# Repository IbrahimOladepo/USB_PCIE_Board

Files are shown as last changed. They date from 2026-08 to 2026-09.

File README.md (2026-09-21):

# USB PCIe Expansion Card

A PCI Express x1 to USB 3.0 expansion card, designed in KiCad. Plugs into a PCIe x1
slot and breaks it out to four USB 3.0 Type-A ports.

## Contents

- [Overview](#overview)
- [Board](#board)
- [Design approach](#design-approach)
- [First assembled board (v0.1)](#first-assembled-board-v01)
  - [The R25 bring-up bug and the through-hole fix](#the-r25-bring-up-bug-and-the-through-hole-fix)
  - [Running in a PC](#running-in-a-pc)
  - [Known issues](#known-issues-to-fix-in-the-next-revision)
- [Component sorting tray](#component-sorting-tray)
- [OS / driver setup](#os--driver-setup)
  - [Windows](#windows)
  - [Linux](#linux)
- [Repository layout](#repository-layout)
- [Status](#status)

## Overview

The design is built around **U1**, a Renesas `µPD720201` xHCI USB 3.0 host
controller, which bridges the PCIe link to four independent USB 3.0 ports.

| Function | Reference(s) | Part |
|---|---|---|
| PCIe x1 edge connector | J1 | `Bus_PCI_Express_x1` |
| USB host controller | U1 | Renesas `UPD720201K8-701-BAC-A` |
| Controller firmware/config flash | U2 | `MX25L4006EM1I-12G` (SPI NOR) |
| Controller clock | X1 | 24MHz crystal |
| USB 3.0 Type-A ports | J2–J5 | Molex `48406-0001` |
| Per-port VBUS power switches | U8–U11 | `AP2191SG-13` |
| Per-port ESD protection | U12–U15 | `SP3011-06UTG` |
| Power regulation | U3, U4, U5, U7 | Buck regulators + 3.3V LDO |

Power for the board and its 5V VBUS rails is derived from the PCIe slot's 12V/3.3V
supply through an on-board regulation chain.

## Board

- 4-layer, ~98.6 x 111.9mm
- ~175 components, ~126 nets

| Top | Bottom |
|---|---|
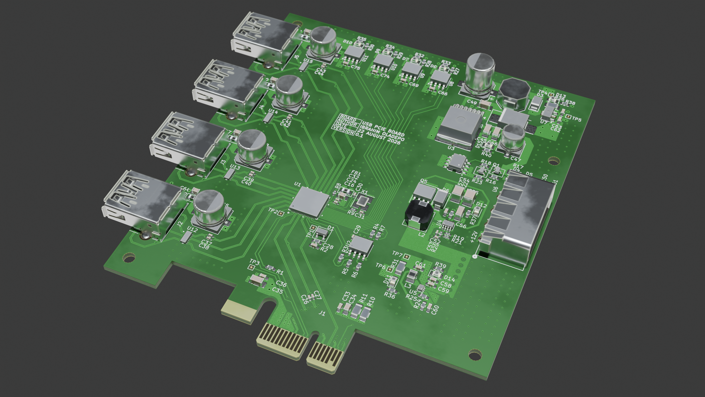
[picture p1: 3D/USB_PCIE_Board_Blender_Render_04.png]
Top isometric render
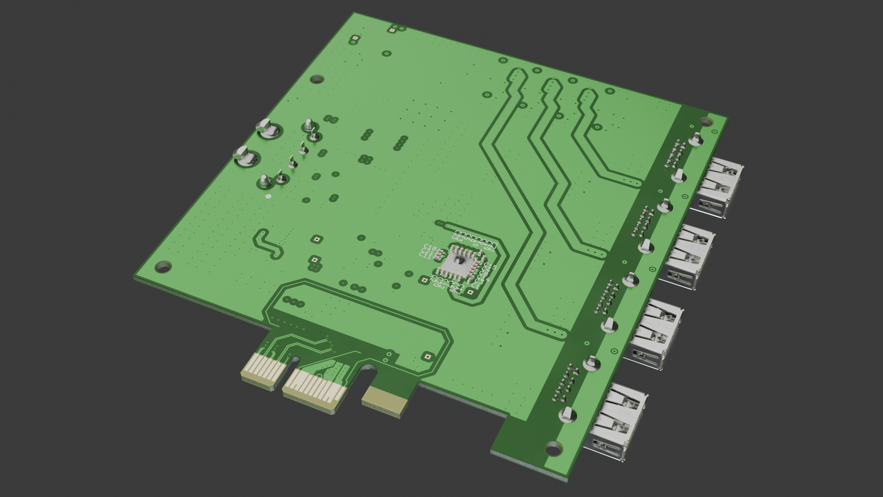
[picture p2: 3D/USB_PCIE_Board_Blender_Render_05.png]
Bottom isometric render
|  |  |

## Design approach

- **All tracks were routed by hand.** No autorouter and no AI-generated routing was
  used.
- **The layer stackup was worked out by me**, following recommendations from
  experts such as Rick Hartley.
- **Claude (Anthropic's AI assistant) was used for repository version control and as
  a second pair of eyes for checking nets for errors.** It did not route or place
  anything. Layout and design decisions are my own.

## First assembled board (v0.1)

| Top | Bottom |
|---|---|
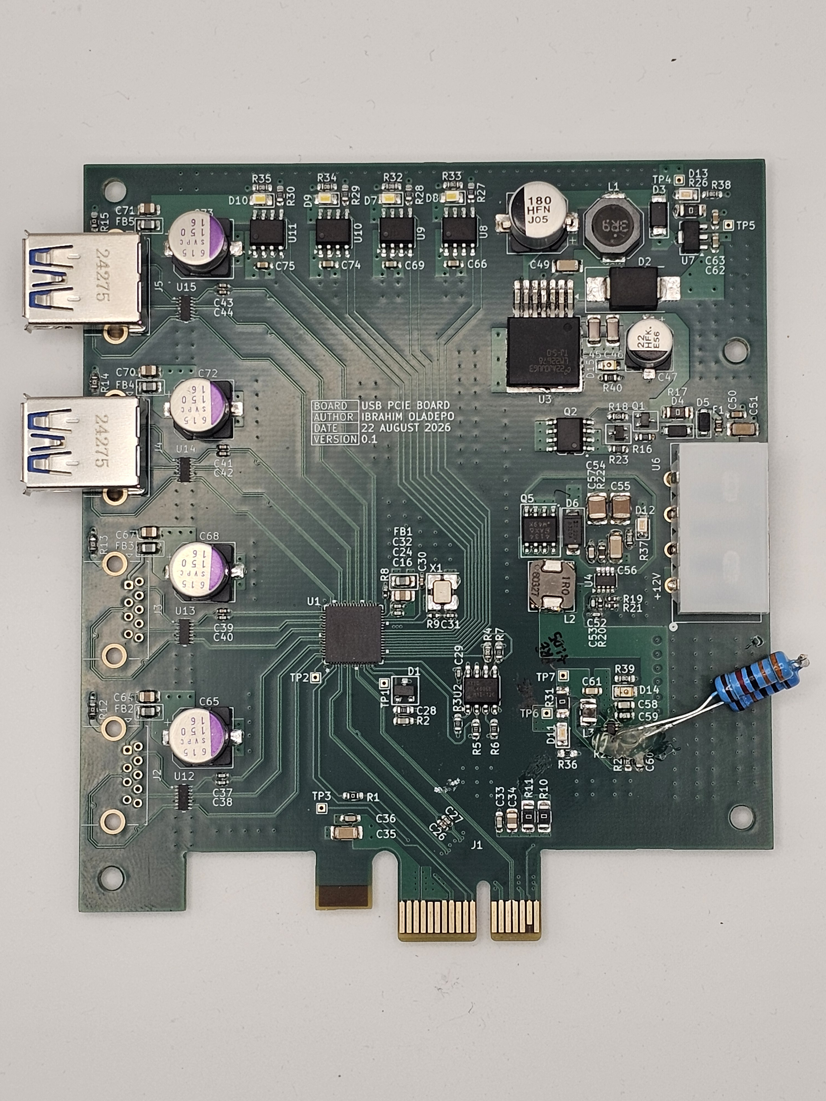
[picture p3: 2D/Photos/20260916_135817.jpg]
Top view, assembled v0.1
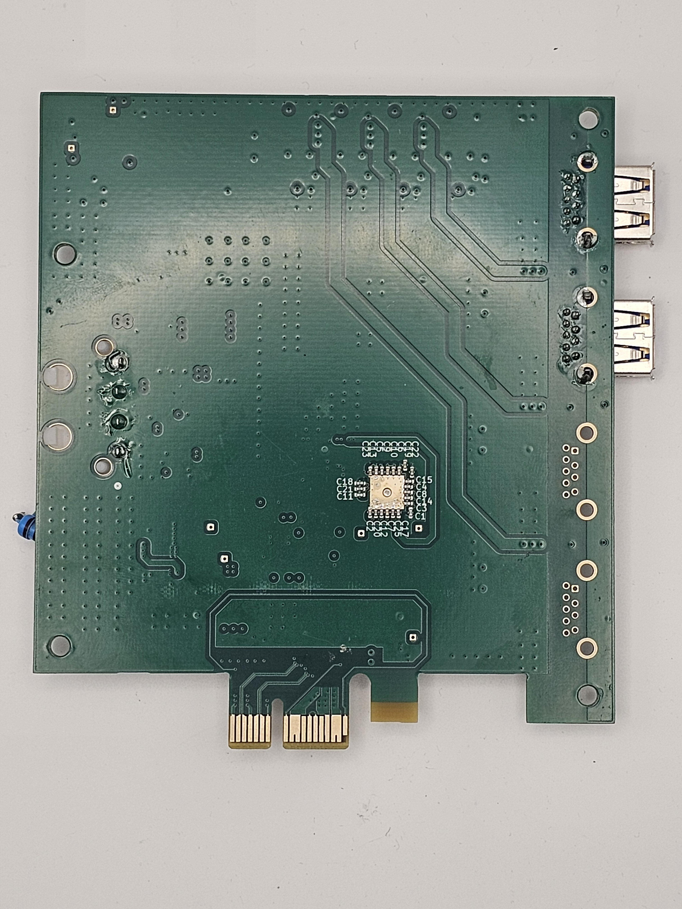
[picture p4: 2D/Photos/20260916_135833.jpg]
Bottom view, assembled v0.1
|  |  |

### The R25 bring-up bug and the through-hole fix

The first populated board brought up all rails cleanly except the 1.05V core rail
(U5), which came up equal to its input voltage instead of regulating. Bring-up debug
(solder-bridge check, continuity check, a U5 swap that didn't help) eventually traced
it to the feedback divider: **R25 had been sourced as a 133Ω part instead of the
133kΩ the design called for**, a unit typo (Ω vs kΩ) that slipped through to the BOM
and the order. With R24 (100kΩ, correct) on top and a 133Ω part on the bottom, the
feedback node was pulled to nearly 0V, which made the regulator's control loop drive
close to 100% duty cycle: output tracking input, exactly as observed.

The through-hole resistors visible in the top-view photo (bottom right, near L3/D14)
are the quick fix: a **100kΩ + 33kΩ series pair (133kΩ total)** from parts already on
hand, soldered in place of the bad R25 so the divider is back at its design value
(1.05V output) without waiting on a new part order.

### Running in a PC

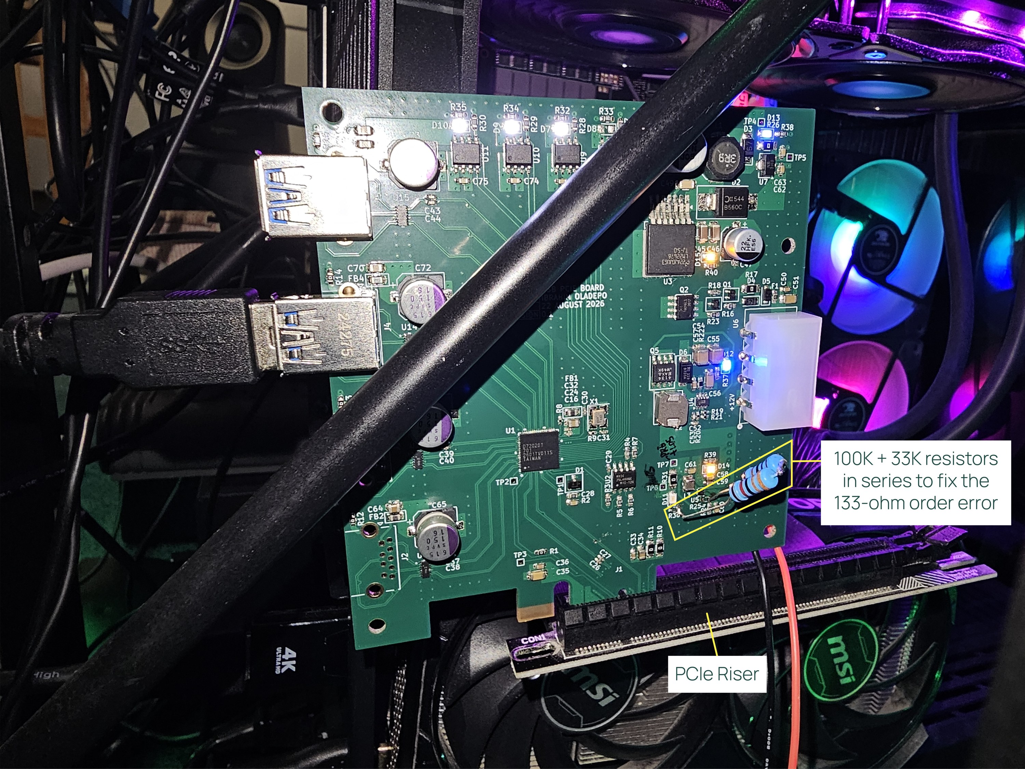
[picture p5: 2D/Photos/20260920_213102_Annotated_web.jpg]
v0.1 board running in a PC through a PCIe riser, with the R25 fix and riser annotated


The board is plugged into the PC's PCIe slot through a **PCIe riser**, for two
reasons: it makes the board easy to probe with a multimeter while powered, and the
case has no room for the board's USB connector placement when seated directly in the
slot. The annotated photo marks the R25 fix and the riser. The original,
un-annotated photo is
[`2D/Photos/20260920_213102.jpg`](2D/Photos/20260920_213102.jpg).

A 1TB SSD connected to one of the board's USB ports, tested with CrystalDiskMark:

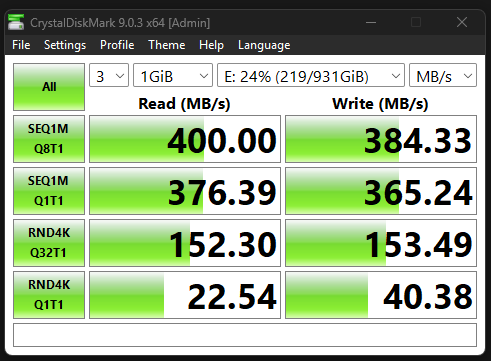
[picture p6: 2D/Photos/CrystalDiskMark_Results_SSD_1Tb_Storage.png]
CrystalDiskMark results for a 1TB SSD on the board


| Test | Read (MB/s) | Write (MB/s) |
|---|---|---|
| SEQ1M Q8T1 | 400.00 | 384.33 |
| SEQ1M Q1T1 | 376.39 | 365.24 |
| RND4K Q32T1 | 152.30 | 153.49 |
| RND4K Q1T1 | 22.54 | 40.38 |

### Known issues (to fix in the next revision)

- **1.05V indicator LED (D11) cannot light.** D11 is a blue `SMLMN2BCTT86C` with a
  forward voltage of about 2.9V, but it is wired across the 1.05V rail, so it can
  never turn on. Note that swapping to a lower-Vf colour will not fix this on its own:
  a red/yellow/green LED still needs roughly 1.8V or more. Options for v0.2: drive
  the LED from +3V3 through a resistor and switch it with a small transistor sensed
  from +1V05, or drop the LED and rely on the TP6/TP7 test points.
- **R25 value.** Re-check the schematic/BOM value and the ordered part for R25 so they
  match the intended 133kΩ before the next order.
- See [`Doc/PCB_Design_Review_Checklist.md`](Doc/PCB_Design_Review_Checklist.md) for the
  rest of the v0.1 review notes.

## Component sorting tray

A 150 x 150 x 10mm box-and-lid pair for sorting the BOM by hand before assembly, one
compartment per distinct part/value. Generated with the
[box-stl-generator](https://javisperez.github.io/box-stl-generator/) tool; STL files
are in `3D/Assembly/`. Pair it with `Doc/Component_Tray_Layout.pdf` for a printable,
to-scale cut-out label plus a lookup table mapping each compartment to its BOM entry.

| Box | Lid |
|---|---|
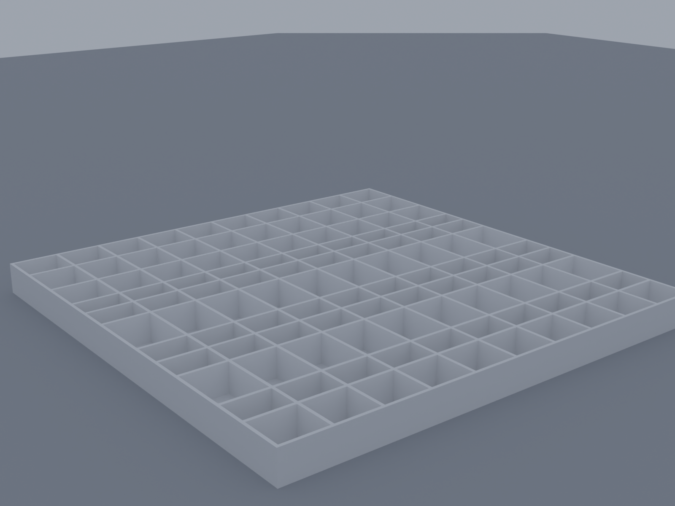
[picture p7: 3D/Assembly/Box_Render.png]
Box render
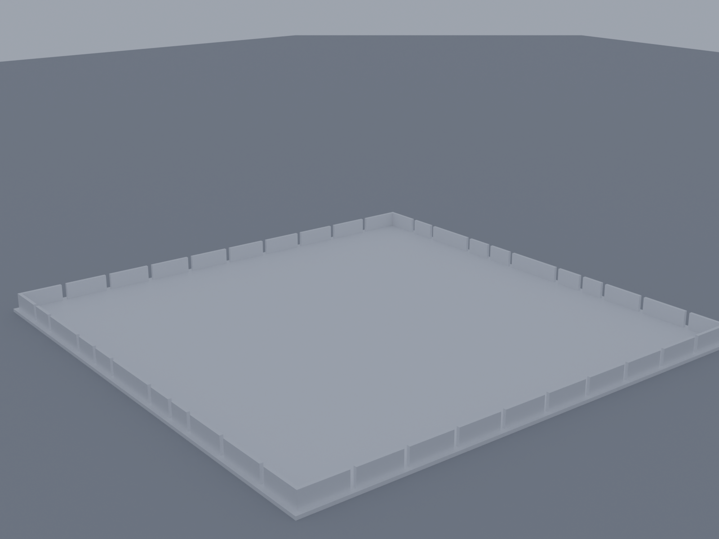
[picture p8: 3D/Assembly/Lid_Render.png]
Lid render
|  |  |

## OS / driver setup

### Windows

Windows Update alone was enough to bring the controller up correctly. In addition, the
[Renesas USB 3.0 Host Controller Driver](https://www.dell.com/support/home/en-fm/drivers/driversdetails?driverid=1ptn7)
(distributed via Dell's driver site) was installed. No manual firmware extraction step
was needed on Windows, unlike Linux.

### Linux

This board uses the Renesas `UPD720201K8-701-BAC-A` PCIe to USB 3.0 host controller. On
Linux, the `xhci-pci-renesas` driver requires a firmware blob to bring the controller
online. That firmware is not distributed through the standard `linux-firmware` package
due to Renesas licensing restrictions, so it has to be installed manually. The steps
below worked on Ubuntu (kernel 7.0.x).

**1. Confirm the board is enumerating on PCIe**

Before touching firmware, confirm the OS sees the chip at all:

```bash
lspci -d 1912:
```

If nothing shows up, this is a hardware bring-up issue (power sequencing, REFCLK/PERST#
timing, card edge connector, or PCIe slot lane availability), not a firmware issue.
Check `sudo dmesg | grep -iE "pci|xhci"` around boot time for enumeration messages
before proceeding.

Once the chip enumerates correctly, you'll see something like:

```
xhci-pci-renesas 0000:01:00.0: probe with driver xhci-pci-renesas failed with error -2
```

The `-2` (ENOENT) confirms the driver bound successfully but could not find the
firmware file.

**2. Get the firmware**

The `linux-firmware` package does not ship `renesas_usb_fw.mem` for this chip family.
Use the community-maintained mirror instead, which repackages the firmware extracted
from Renesas's official Windows update tool along with checksums:

```bash
cd /tmp
wget https://github.com/chunkeey/renesas-fw/raw/master/USB3-201-202-FW-20120615.zip
wget https://github.com/chunkeey/renesas-fw/raw/master/SHA256SUMS
sha256sum -c SHA256SUMS 2>/dev/null | grep -i ok
unzip USB3-201-202-FW-20120615.zip -d renesas-fw-extracted
```

This covers both the uPD720201 and uPD720202 with a single combined firmware image:
`K2013080.mem`.

**3. Install the firmware**

```bash
sudo cp /tmp/renesas-fw-extracted/USB3-201-202-FW-20120615/K2013080.mem /lib/firmware/renesas_usb_fw.mem
file /lib/firmware/renesas_usb_fw.mem   # should report "data", not ASCII/HTML
sudo update-initramfs -u
sudo reboot
```

**4. Verify**

```bash
sudo dmesg | grep -i renesas
lsusb
```

Expected output on success:

```
xhci-pci-renesas 0000:01:00.0: xHCI Host Controller
xhci-pci-renesas 0000:01:00.0: new USB bus registered, assigned bus number 3
xhci-pci-renesas 0000:01:00.0: new USB bus registered, assigned bus number 4
xhci-pci-renesas 0000:01:00.0: Host supports USB 3.0 SuperSpeed
usb 4-1: new SuperSpeed USB device number 2 using xhci-pci-renesas
```

A device plugged into the hub should now show up in `lsusb` as a SuperSpeed device on
the new bus.

**Notes**

- This firmware image is dated 2012. Renesas has released newer versions since; if you
  hit driver errors that this image does not resolve, pull an updated version directly
  from Renesas's site (free account required) rather than a community mirror.
- Because the firmware is not redistributable through `linux-firmware`, this manual
  install step will need to be repeated after a fresh OS install or if `/lib/firmware`
  gets wiped. Consider scripting steps 2 to 3 as a setup script in this repo for future
  bring-up.

## Repository layout

- `USB_PCIE_Board.kicad_pro` / `.kicad_pcb` / `.kicad_sch` — main project, board, and schematic
- `USB_PCIE_BOARD_POWER.kicad_sch` — power supply schematic sheet
- `Doc/` — documentation, including a PCB design review checklist and the component
  tray layout
- `2D/` — board edge outline drawings (`.dxf` / `.ai`), and `2D/Photos/` with photos of
  the assembled v0.1 board and its bring-up
- `3D/` — Blender renders and STEP/pcb3d exports of the board; `3D/Assembly/` has the
  sorting tray's STL files and renders
- `bom/` — interactive HTML BOM (`ibom.html`)
- `production/` — generated fabrication outputs (gerbers, BOM, position files)

## Status

Actively being worked through a design review pass (DRC cleanup, courtyard/footprint
fixes, silkscreen check) — see `Doc/PCB_Design_Review_Checklist.md` for the current
punch list.

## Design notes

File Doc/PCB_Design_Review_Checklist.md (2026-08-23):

# PCB Design & Review Checklist

Source: [Altium — PCB Design and Review Checklist](https://resources.altium.com/p/pcb-design-and-review-checklist)
(Mark Harris, updated 2026-08-10). Full article saved at
`Doc/PCB Design Review Checklist _ Blog _ Altium.PDF`.

> Per the article: treat each item as a **discussion point**, not just a box to tick —
> the goal is confirming the design meets intent, not just clearing a checklist. Not
> every item applies to every board; mark N/A with a short reason rather than deleting
> a line, so the reasoning is preserved for next time.

Check items off as `[x]` as we work through the design. Notes on findings go inline
under each item.

**Review pass 2026-08-22** (via KiCAD MCP tools — DRC, courtyard/boundary check, zone
query, ratsnest, board geometry). Items with a **Findings:** line were checked against
the live board; everything else needs a manual/visual pass (silkscreen artwork,
mechanical fit, simulation) that wasn't possible from this session.

## Before Submitting for Review

- [x] Check for unrouted nets
  - **Findings:** No unconnected-items errors in DRC; board shows 1315 tracks / 575 vias
    across 126 nets. Appears fully routed.
- [ ] Repour all polygons
  - **Findings:** All 92 copper zones report `isFilled: true` in the current save — no
    stale/unfilled zones detected. Still worth doing an explicit "Refill All Zones" +
    re-save right before final DRC, since this only reflects the last fill on disk.
- [ ] Complete silkscreen, including:
  - [ ] Company logo(s) — not checkable via this tooling, visual check needed
  - [ ] Product logo(s) — visual check needed
  - [ ] Copyright notice — visual check needed
  - [ ] Warning/hazard label(s) and icons — visual check needed (likely N/A, board carries no hazardous voltages)
  - [ ] Connectors labeled, pinouts called out where relevant — visual check needed
  - [ ] QA/Test block with barcode, blank areas for serial number, dates, QA/Test checkmarks — not found in any pass this session; likely missing
  - [ ] Board name, print date, and revision number — title block metadata exists (title "USB PCIE Expansion Card Board", rev "0.1") but that's project metadata, not confirmed to be rendered as silkscreen text — visual check needed
  - [x] If there are designators on the silkscreen, then check:
    - [x] Each designator close to and clearly identifies its component
    - [x] All designators only in one or two orientations
    - [x] Text size/font legible after fabrication
    - **Findings:** DRC found 1 `silk_overlap` warning near U1 (86.82, 111.34mm) and 8
      `silk_edge_clearance` warnings **all at the same point** — the board's bottom-left
      corner (51.45, 145.26mm), right by the PCIe-connector notch. Something on
      silkscreen there is being clipped by the board edge — worth a direct look at that
      corner.
  - [x] ICs have pin-1 clearly marked (not under another component) — visual check needed
- [x] PCB updated from schematic — schematic and board are synchronized
  - **Findings:** Mounting holes (H1–H4) were just added to the schematic to match the
    board this session. Re-run "Update PCB from Schematic" once more to confirm there's
    nothing else outstanding.
- [ ] Design rule report passes with no errors
  - **Findings: currently fails — 257 errors, 15 warnings (272 total).** Breakdown:
    - **199 × `via_dangling` (error)** — by far the largest bucket (77% of all errors).
      "Via is not connected or connected on only one layer." Locations are spread
      broadly around the board perimeter and near GND-heavy areas, consistent with GND
      stitching vias that only land on the inner plane on one side. This is the single
      highest-leverage fix — resolving it clears most of the error count.
    - **50 × `hole_clearance` (error)** — all reported as ~0.186–0.197mm actual vs.
      0.200mm required (off by hundredths of a mm), tightly clustered around
      x 85–92mm / y 101–111mm — exactly U1's decoupling-capacitor via fan-out. See the
      Signal Path section below.
    - **8 × `malformed_courtyard` (error)** — same footprint, at 4 evenly-spaced
      y-positions (52.5, 75.8, 99.0, 122.5mm) matching the 4 USB port rows — this is the
      ferrite bead footprint used at FB2–FB5 (one per port). The courtyard on that
      footprint isn't a closed shape — a footprint-library definition issue, not a
      placement issue, so fixing the footprint fixes all 4 instances at once.
    - **5 × `lib_footprint_mismatch` (warning)** — H1, H2, H3, H4
      (`MountingHole_3.2mm_M3`) and J1 (`BUS_PCIexpress_x1`) have all diverged from
      their library originals. Needs a decision: accept the local edits, or
      "Update Footprint from Library" to resync.
    - **1 × `silk_overlap` (warning)** near U1 (86.82, 111.34mm) — see silkscreen note above.
    - **1 × `copper_sliver` (warning)** on F.Cu — no precise location reported by the tool.
  - [ ] A design rule exists to catch nets with only 1 pin — not directly checkable via
        DRC; this is normally an ERC (schematic) check — recommend running ERC.
- [x] Board outline present on a mechanical layer that goes to the fabricator
  - **Findings:** Present — 25 Edge.Cuts segments/arcs forming a closed outline,
    98.64 × 111.9mm extents.
- [ ] Fiducials present for assembly:
  - [ ] Minimum three board-level fiducials included
  - [ ] Two fiducials diagonally opposing each other across all extremely fine-pitch components
  - **Findings: none found.** No footprint with "fiducial" in its name or footprint
    library reference appears anywhere on the board. Given U1 is a QFN68 at 0.4mm pitch,
    fiducials are worth adding before this goes to an assembler.
- [ ] Mounting points have sufficient clearance for the chosen washer and screw head
  - **Findings:** H1–H4 exist as M3 holes (3.2mm drill), but exact copper/silk clearance
    against a specific washer spec wasn't checked. One thing worth confirming visually:
    C71's courtyard overlaps H1's courtyard by ~0.86mm² — make sure the cap doesn't
    physically conflict with a washer at that hole.
- [ ] If an enclosure model is available, it's been tested against the board
  - [ ] All components (including mechanical items) have accurate 3D models
  - Not checkable this session — no enclosure model was referenced. Manual step if this board is going into an enclosure.

## Layers

- [x] Layer stack and substrate heights meet the fabricator's specifications
  - **Findings:** 4 copper layers confirmed via the gerber export (F.Cu, In1.Cu, In2.Cu, B.Cu).
- [x] Copper thickness on all layers matches the fabricator's spec
  - Not checked against a specific fab's stackup table — compare against your chosen
    fab's (e.g. JLCPCB) published stackup before ordering.
- [x] At least one continuous, unbroken ground plane
  - **Findings:** In1.Cu carries a single GND zone spanning ~9310mm² of the ~11000mm²
    board area — reads as the dedicated ground-plane layer.
- [x] Controlled-impedance nets correctly set up in both the layer stack and design rules
  - **Findings:** `get_design_rules` only surfaced one global clearance/track-width rule
    set (0.09mm min clearance, 0.2mm default track width) — no per-netclass differential
    pair rule was visible from this tool. Worth confirming directly in KiCad that the
    USB3 SuperSpeed pairs and PCIe lanes have their own netclass with a differential
    width/gap tuned to 90Ω for your actual stackup.
  - Also flagged: the board's default min clearance/trace width (0.09mm / ~3.5 mil) is
    tighter than many standard-tier fab processes support (commonly 5 mil / 0.127mm
    minimum) — worth double-checking your fab can hit this, unless it was intentionally
    set for an HDI-capable process.
- [x] Any keep-out track matches the board shape
  - [x] Board cutouts/slots have keep-out barriers to prevent nets crossing milled areas
  - Not checked this session.

## Signal Path

- [x] Differential pair tracks are as close together as possible / lengths matched
  - **Findings:** 0 diff-pair-related DRC violations found now, consistent with the
    "Fix skew on differential pair lines" work already in the commit history.
- [ ] Decoupling capacitor vias are not shared — each cap has its own via for VCC and GND
  - **Findings:** U1 has ~30 decoupling caps packed tightly around it — courtyard scan
    shows many overlapping U1's own courtyard boundary by ~2.29mm² each, with vias
    clustered at x 85–92mm / y 101–111mm — the same region producing the 50
    `hole_clearance` DRC errors above. These two findings point at the same spot: worth
    a dedicated look at whether adjacent caps' vias are packed tighter than the 0.2mm
    hole-clearance rule allows.
- [ ] Everything else in this section (via sizing for current capacity, reference-plane
      track width, controlled-impedance profile continuity, crosstalk simulation,
      termination placement) — not checkable from static geometry alone; needs
      simulation or a dedicated manual pass.

## Components

- [x] Courtyard overlaps / clearance
  - **Findings:** `check_courtyard_overlaps` found 83 overlapping courtyard pairs (many
    are tight-packed 0402/0201 decoupling caps around U1 and connector-area parts —
    common in dense fan-out, but worth a skim) and, more notably, **5 boundary
    violations against the board edge**:
    - **J1** (PCIe edge connector) exceeds the board's bottom edge by 0.33mm
    - **J2, J3, J4, J5** (USB-A connectors) each exceed the board's left edge by 7.4mm
  - The USB-connector overhang is very likely intentional — horizontal Type-A shells
    commonly cantilever past the PCB edge into the port opening — but worth a 3D-view
    check to confirm the shells land where an enclosure/bracket expects them. J1's
    0.33mm overhang is worth a closer look specifically: PCIe card-edge fingers need a
    precise setback from the physical board edge per the PCIe CEM spec, so confirm this
    isn't the golden fingers themselves creeping past where they should be.
- [x] Bypass capacitors placed close to IC power pins (under 15mm)
  - **Findings:** U1's decoupling caps sit within ~1–2.3mm of its pins — well under the
    15mm guideline.
- [ ] Everything else (pick-and-place/hand-assembly/rework clearance, crystal-to-clock-pin
      distance, termination-resistor placement, EMI/RFI filter placement, potentiometer
      direction, thermal-mass separation, heat-sinking copper area) — not checkable from
      this data; needs a visual/BOM-level pass.

## Testing

- [ ] Test point inventory and placement
  - **Findings:** Test points exist (at least TP2, TP6 seen in this session's queries),
    but a full inventory, side-consistency check (all on one side), and edge-clearance
    check weren't completed. Worth a manual pass to confirm every rail and every
    diff pair you'd want to probe has one, and they're all reachable from the same side.

## Protection / EMI / EMC

- [x] ESD mitigation components in series with the protected signal
  - **Findings:** U12–U15 (SP3011-06UTG TVS diode arrays) are wired one per USB port,
    matching the "ESD event must pass through the component before reaching a sensitive
    device" requirement. Exact routing order (TVS before host controller pins) wasn't
    independently re-verified pad-by-pad this session.
- [ ] Everything else (creepage/clearance for high-voltage nets — likely N/A, board
      carries no mains voltage; ground loops; track width vs. current for +12V/+5V
      rails; RF shield footprint) — not checked in this pass.

## Panels

*Only applies if this board is being ordered/assembled as part of a multi-board panel.*

- **N/A** — the `production/` export is single-board gerbers, not a panel.

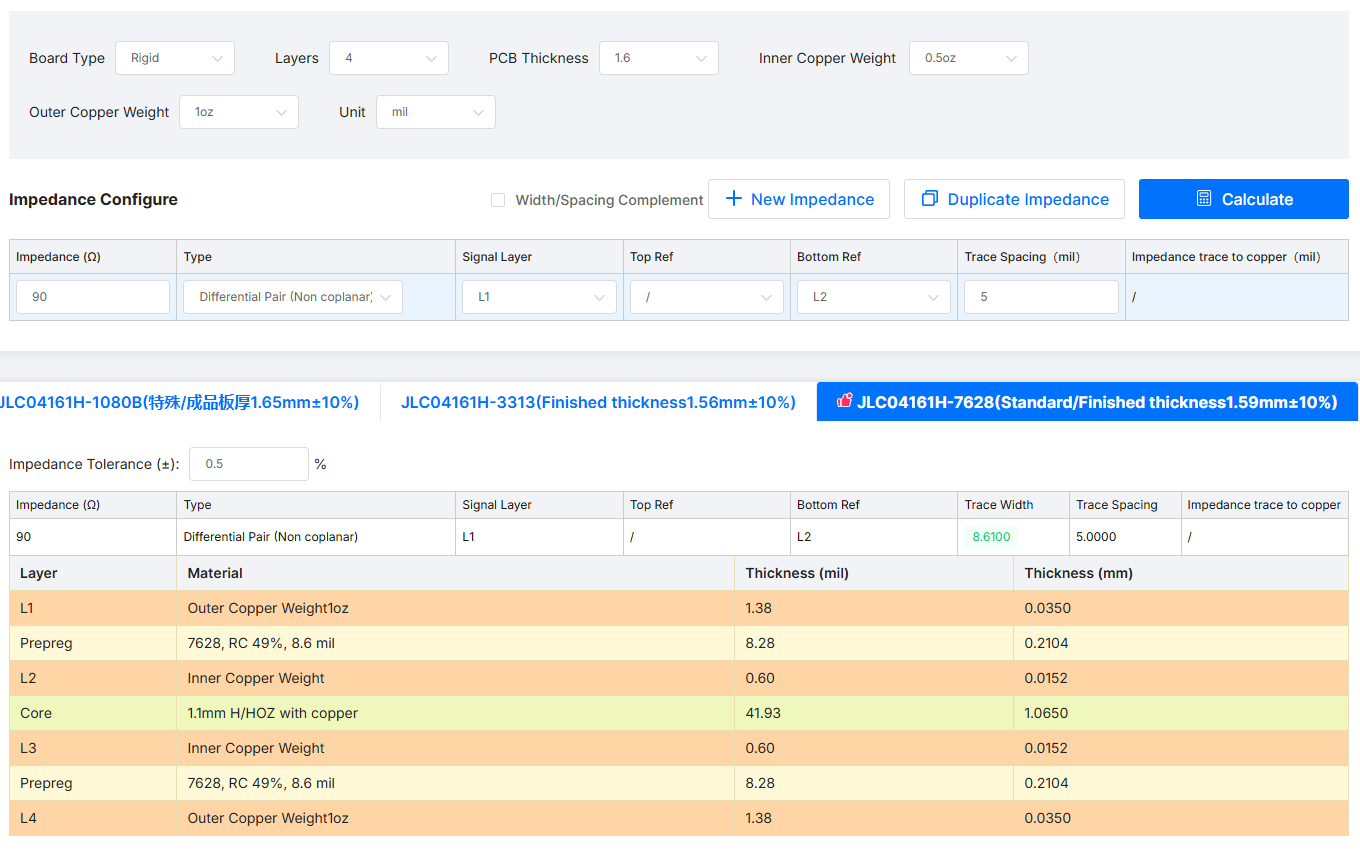
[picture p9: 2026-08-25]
Doc/JLCPCB_Impedance_Calculation.png

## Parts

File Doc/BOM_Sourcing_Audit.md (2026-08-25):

# BOM Sourcing Audit (JLCPCB/LCSC)

Checked 2026-08-23 against a local snapshot of the JLCPCB parts catalog (633,703
in-stock parts, downloaded via the KiCad MCP JLCPCB integration). Source BOM:
`production/USB_PCIE_Board.csv`.

## Headline finding

Every part present in the snapshot has a first price-break tier of **"1+"** — none
carry a JLCPCB SMT-assembly MOQ above 1 unit. The high-MOQ warning seen on LCSC's site
is most likely their separate loose-part/reel retail MOQ, not the JLCPCB assembly MOQ
this database tracks. Worth confirming which flow (assembly vs. loose-part purchase)
produced that warning before resourcing anything below.

Real issues found instead: one part with insufficient stock for the quantity needed,
three parts not present in the local snapshot, and near-universal Extended library
type (a cost issue, not a MOQ/stock issue).

## Full part table

| Ref(s) | Qty | Original LCSC# | MOQ (1st tier) | Stock | Library | Status | Suggested Alternative |
|---|---|---|---|---|---|---|---|
| C1-C17 | 17 | C60133 | 1 | 3,311 | Extended | OK | — |
| C18-C27,C29,C37-44 | 19 | C60474 | 1 | 10,000 | Extended | OK | — |
| C28,C62,C63,C66,C69,C74,C75 | 7 | C29936 | 1 | 178,930 | Extended | OK | — |
| C30,C31 | 2 | C2191663 | 1 | 29,868 | Extended | OK | — |
| C32,C34,C64,C67,C70,C71 | 6 | C326595 | 1 | 3,754 | Extended | OK | — |
| C33,C36,C50,C57,C59 | 5 | C14663 | 1 | 12,618,106 | Basic | OK | — |
| C35,C51,C56 | 3 | C162437 | 1 | 4,162 | Extended | OK | — |
| C45,C46 | 2 | C342646 | 1 | 1,810 | Extended | OK | — |
| C47 | 1 | C128458 | 1 | 3,852 | Extended | OK | — |
| C48 | 1 | C494858 | 1 | 126 | Extended | OK (thin stock) | — |
| C49 | 1 | C106239 | 1 | 51,862 | Extended | OK | — |
| C52 | 1 | C107024 | 1 | 123,326 | Extended | OK | — |
| C53 | 1 | C60137 | 1 | 2,128,208 | Extended | OK | — |
| C54,C55 | 2 | C23742 | 1 | 4,743 | Extended | OK | — |
| C58,C60,C61 | 3 | C77042 | 1 | 421,317 | Extended | OK | — |
| C65,C68,C72,C73 | 4 | C190722 | 1 | 725 | Extended | OK | — |
| D1 | 1 | C261914 | 1 | 26,448 | Extended | OK | — |
| D2 | 1 | C85100 | 1 | 212,196 | Extended | OK | — |
| D3 | 1 | C253526 | 1 | 3,022 | Extended | OK | — |
| D4,D5 | 2 | C2845139 | 1 | 3,031 | Extended | OK | — |
| D6 | 1 | C110484 | 1 | 6,374 | Extended | OK | — |
| D7-D10 | 4 | C2992528 | 1 | 2,680 | Extended | OK | — |
| D11-D13 | 3 | C2837824 | 1 | 28,334 | Extended | OK | — |
| D14,D15 | 2 | C5588998 | 1 | 3,060 | Extended | OK | — |
| F1 | 1 | C1972746 | 1 | 53 | Extended | OK (thin stock) | — |
| FB1-FB5 | 5 | C18305 | 1 | 132,019 | Extended | OK | — |
| J2-J5 | 4 | C6376748 | 1 | 123 | Extended | OK (thin stock) | none — connector, no safe swap |
| L1 | 1 | C2045037 | 1 | 100 | Extended | OK | — |
| L2 | 1 | C87572 | 1 | 21,781 | Extended | OK | — |
| L3 | 1 | C909806 | 1 | 750 | Extended | OK | — |
| Q1 | 1 | C111698 | 1 | 10,686 | Extended | OK | — |
| Q2 | 1 | C111700 | 1 | 20,055 | Extended | OK | — |
| Q4 | 1 | C151586 | 1 | 2,554 | Extended | OK | none — specific MOSFET, no safe swap |
| Q5 | 1 | C142600 | 1 | 12,902 | Extended | OK | none — specific MOSFET, no safe swap |
| R1,R12-R15 | 5 | C95177 | 1 | 477,935 | Extended | OK | — |
| R2,R3,R5,R6,R7,R16,R23,R27,R28,R29,R30,R40 | 12 | C159891 | — | — | — | Not found in DB | C1511834 CRCW060310K0JNEBC — 10K 0603 5%, MOQ 1, 9,377 stock, Extended (best same-package match; no Basic 0603 10K in this snapshot) |
| R4,R24 | 2 | C14675 | 1 | 5,999 | Extended | OK | — |
| R8 | 1 | C413085 | 1 | 967 | Extended | OK | — |
| R9 | 1 | C413078 | 1 | 15,078 | Extended | OK | — |
| R10,R11,R17,R26,R31 | 5 | *(none given)* | — | — | — | No LCSC# given | C408932 CR-06JA7----0R — 0Ω 1206 jumper, MOQ 1, 5,051 stock, Extended (no Basic 0Ω 1206 found) |
| R18 | 1 | C127447 | 1 | 91,974 | Extended | OK | — |
| R19 | 1 | C1883521 | 1 | 303 | Extended | OK | — |
| R20 | 1 | C481960 | — | — | — | Not found in DB | C2933077 FRC0402F1742TS — 17.4K 0402 1%, MOQ 1, 129,307 stock, Extended |
| R21 | 1 | C2076772 | 1 | 35,568 | Extended | OK | — |
| R22 | 1 | C844922 | 1 | 19,789 | Extended | OK | — |
| R25 | 1 | C2076703 | 1 | 1,801 | Extended | OK | — |
| R32-R39 | 8 | C22548 | 1 | 5 | Extended | **Stock too low (5 in stock, 8 needed)** | C21190 0603WAF1001T5E — 1K 0603 1%, MOQ 1, 8,013,731 stock, Basic |
| U1 | 1 | C355375 | 1 | 1,089 | Extended | OK | none — host controller, no safe swap |
| U2 | 1 | C56001 | 1 | 34 | Extended | OK (thin stock) | none — specific flash, no safe swap |
| U3 | 1 | C527397 | 1 | 1,180 | Extended | OK | — |
| U4 | 1 | C459876 | 1 | 40 | Extended | OK (thin stock) | none — specific controller, no safe swap |
| U5 | 1 | C5896722 | 1 | 594 | Extended | OK | — |
| U6 | 1 | C706976 | 1 | 8,341 | Extended | OK | — |
| U7 | 1 | C460367 | 1 | 1,655 | Extended | OK | — |
| U8-U11 | 4 | C2150698 | 1 | 701 | Extended | OK | — |
| U12-U15 | 4 | C207281 | 1 | 2,555 | Extended | OK | — |
| X1 | 1 | C20010545 | — | — | — | Not found in DB | see notes — no verified pin/load-cap match confirmed |

Not checked: J1 (PCIe edge connector — card-edge finger pattern on the PCB itself, not
a purchasable part) and TP1-TP7 (generic through-hole test points, not LCSC-sourced).

## Notes / needs your judgment

1. **R32–R39 (C22548) is the one genuine stock risk**: 5 in stock, 8 needed. Suggested
   drop-in: C21190 (0603WAF1001T5E), same 1kΩ/0603/1% spec, Basic library (saves the $3
   setup fee too), 8M+ stock.
2. **Three parts aren't in the local snapshot**: R2-group (C159891), R20 (C481960), and
   X1 (C20010545). Could be delisted/renumbered since the snapshot was taken, or a
   transcription issue in the BOM — verify directly on LCSC.com before ordering. For X1
   specifically, do **not** treat the suggested alternates as verified drop-ins — load
   capacitance and pinout weren't confirmed against the NDK CS14522-24M, and clock
   accuracy matters for U1 (the USB3 host controller). Check the datasheet before
   substituting.
3. **55 of 57 line items are Extended library**, each carrying JLCPCB's $3/unique-part
   setup fee regardless of quantity — roughly $165+ in setup fees baked into this BOM.
   Only C14663 (0.1uF 0603 X7R 50V) is Basic. Worth a look if assembly cost matters more
   than exact spec match, though no Basic equivalents turned up for the other passives
   in this pass.
4. **No substitutions were suggested for any IC, MOSFET, connector, or crystal**
   (U1-U15, Q4, Q5, J2-J5, X1) unless a confirmed pin/function-identical part was found —
   where nothing safe turned up, the table says so rather than guessing.

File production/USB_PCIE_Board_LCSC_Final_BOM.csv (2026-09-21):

LCSC Part Number | Manufacture Part Number | Manufacturer | Customer NO. | Package | Description | RoHS | Quantity | Unit Price($) | Ext.Price($) | Estimated lead time (business days) | Updated lead time | Date Code / Lot No.
C14663 | CC0603KRX7R9BB104 | YAGEO | C33,C36,C50,C57,C59 | 0603 | 100nF ±10% 50V Ceramic Capacitor X7R 0603 | YES | 50 | 0.0151 | 0.76
C60474 | CC0402KRX7R7BB104 | YAGEO | C18,C19,C20,C21,C22,C23,C24,C25,C26,C27,C29,C37,C38,C39,C40,C41, | 0402 | 100nF ±10% 16V Ceramic Capacitor X7R 0402 | YES | 100 | 0.0054 | 0.54
C18305 | BLM21PG600SN1D | muRata | FB1,FB2,FB3,FB4,FB5 | 0805 | 60Ω@100MHz 1 Line Ferrite Bead 0805 3.5A 20mΩ | YES | 20 | 0.0402 | 0.80
C1972746 | SF-0603S315-2 | BOURNS | F1 | 0603 | 3.15A Surface Mount 0603 | YES | 2 | 0.5505 | 1.10
C5588998 | APTD2012LSYCK | Kingbright | D14,D15 | 0805 | Yellow 590nm LED Indication - Discrete 1.85V 0805 | YES | 5 | 0.2268 | 1.13
C2837824 | SMLMN2BCTT86C | ROHM | D11,D12,D13 | 0805 | Blue 476nm LED Indication - Discrete 2.9V 0805 | YES | 10 | 0.3083 | 3.08
C2992528 | SMLMN2WB1CW1 | ROHM | D7,D8,D9,D10 | 0805 | White LED Indication - Discrete 2.9V 0805 | YES | 10 | 0.3253 | 3.25
C110484 | B320A-13-F | DIODES | D6 | SMA(DO-214AC) | 1 Independent 20V 500mV@3A 3A SMA(DO-214AC) Single Diodes RoHS | YES | 5 | 0.1615 | 0.81
C2845139 | RBR2MM30BTR | ROHM | D4,D5 | SOD-123FL | Diode Independent 30V 2A Surface Mount SOD-123FL | YES | 5 | 0.1398 | 0.70
C253526 | RSX501LAM20TR | ROHM | D3 | SOD-128 | Diode 20V 5A Surface Mount SOD-128 | YES | 5 | 0.2183 | 1.09
C85100 | B560C-13-F | DIODES | D2 | SMC(DO-214AB) | 1 Independent 60V 700mV@5A 5A SMC(DO-214AB) Single Diodes RoHS | YES | 5 | 0.2117 | 1.06
C261914 | 1SS294,LF | TOSHIBA | D1 | SC-59 | Diode 40V 100mA Surface Mount SC-59 | YES | 10 | 0.0594 | 0.59
C190722 | 16SVPC150M | PANASONIC | C65,C68,C72,C73 | SMD,D8xL6.9mm | 150uF ±20% 16V Aluminum - Polymer Capacitors SMD,D8xL6.9mm 2000hrs@105℃ | YES | 8 | 1.1395 | 9.12
C77042 | GRM188R60J226MEA0D | muRata | C58,C60,C61 | 0603 | 22uF ±20% 6.3V Ceramic Capacitor X5R 0603 | YES | 10 | 0.0572 | 0.57
C60137 | CC0402JRNPO9BN470 | YAGEO | C53 | 0402 | 47pF ±5% 50V Ceramic Capacitor NP0 0402 | YES | 100 | 0.0028 | 0.28
C23742 | CL32A107MPVNNNE | Samsung Electro-Mechanics | C54,C55 | 1210 | 100uF ±20% 10V Ceramic Capacitor X5R 1210 | YES | 4 | 0.5051 | 2.02
C108081 | RC1206JR-070RL | YAGEO | R10,R11,R17,R26,R31 | 1206 | 0Ω 250mW 200V Thick Film Resistor ±5% 1206 Chip Resistor - Surface Mount RoHS | YES | 50 | 0.0114 | 0.57
C60133 | CC0402KRX7R9BB103 | YAGEO | C1,C2,C3,C4,C5,C6,C7,C8,C9,C10,C11,C12,C13,C14,C15,C16,C17 | 0402 | 10nF ±10% 50V Ceramic Capacitor X7R 0402 | YES | 100 | 0.0056 | 0.56
C29936 | CL10B105KA8NNNC | Samsung Electro-Mechanics | C28,C62,C63,C66,C69,C74,C75 | 0603 | 1uF ±10% 25V Ceramic Capacitor X7R 0603 | YES | 20 | 0.0216 | 0.43
C2191663 | GJM1555C1H8R0DB01D | muRata | C30,C31 | 0402 | 8pF C0G 50V 0402 Ceramic Capacitors RoHS | YES | 50 | 0.0207 | 1.04
C326595 | CC0805KKX7R7BB106 | YAGEO | C32,C34,C64,C67,C70,C71 | 0805 | 10uF ±10% 16V Ceramic Capacitor X7R 0805 | YES | 15 | 0.2428 | 3.64
C162437 | GRM319R61E106KA12D | muRata | C35,C51,C56 | 1206 | 10uF ±10% 25V Ceramic Capacitor X5R 1206 | YES | 10 | 0.239 | 2.39
C342646 | C3216X7R1V685KT000E | TDK | C45,C46 | 1206 | 6.8uF ±10% 35V Ceramic Capacitor X7R 1206 | YES | 4 | 0.5643 | 2.26
C128458 | EEEFK1H220P | PANASONIC | C47 | SMD,D6.3xL5.8mm | 22uF ±20% 50V Aluminum Electrolytic Capacitors 2000hrs@105℃ | YES | 5 | 0.1618 | 0.81
C494858 | EEEFN1H181UP | PANASONIC | C48 | SMD,D8xL10.2mm | 180uF ±20% 50V Aluminum Electrolytic Capacitors 2000hrs@105℃ | YES | 2 | 0.787 | 1.57
C106239 | CC1206KRX7R9BB103 | YAGEO | C49 | 1206 | 10nF ±10% 50V Ceramic Capacitor X7R 1206 | YES | 20 | 0.0371 | 0.74
C107024 | CC0402KRX7R9BB182 | YAGEO | C52 | 0402 | 1.8nF ±10% 50V Ceramic Capacitor X7R 0402 | YES | 100 | 0.01 | 1.00
C2076772 | CRCW040234K8FKED | VISHAY | R21 | 0402 | 34.8kΩ 62.5mW 50V Thick Film Resistor ±1% ±100ppm/℃ 0402 Chip Resistor - Surface Mount RoHS | YES | 100 | 0.0032 | 0.32
C844922 | CRCW06031M00FKEA | VISHAY | R22 | 0603 | 100mW 1MΩ 75V Thick Film Resistor ±1% ±100ppm/℃ 0603 Chip Resistor - Surface Mount RoHS | YES | 100 | 0.0049 | 0.49
C2076703 | CRCW0603133RFKEA | VISHAY | R25 | 0603 | 133Ω 100mW 75V Thick Film Resistor ±1% ±100ppm/℃ 0603 Chip Resistor - Surface Mount RoHS | YES | 50 | 0.0084 | 0.42
C22548 | RC0603FR-071KL | YAGEO | R32,R33,R34,R35,R36,R37,R38,R39 | 0603 | 100mW 1kΩ 75V Thick Film Resistor ±100ppm/℃ ±1% 0603 Chip Resistor - Surface Mount RoHS | YES | 100 | 0.0052 | 0.52
C56001 | MX25L4006EM1I-12G | MXIC | U2 | SOP-8 | FLASH - NOR Memory IC 4Mbit SPI 86MHz SOP-8 | YES | 2 | 1.0759 | 2.15
C527397 | LM22678TJ-5.0/NOPB | TI | U3 | TO-263-7 | 500kHz Step-down type Fixed 5V 5A TO-263-7 Voltage Regulators - DC DC Switching Regulators RoHS | YES | 2 | 4.9834 | 9.97
C459876 | LTC3872ETS8#TRPBF | ADI | U4 | TSOT-23-8 | 1 Adjustable Boost TSOT-23-8 DC DC Switching Controllers RoHS | YES | 2 | 6.2227 | 12.45
C5896722 | RT5762CHGH6F | RICHTEK | U5 | SOT-563 | 1.2MHz Step-down type Adjustable 2A 600mV~6V SOT-563 Voltage Regulators - DC DC Switching Regulators RoHS | YES | 5 | 0.3323 | 1.66
C706976 | X5050WR-04S-N2SN | XKB Connection | U6 | Through Hole,Right Angle,P=5.08mm | Connector Header 4 position 5.08mm Pitch 10A Right Angle | YES | 5 | 0.2296 | 1.15
C460367 | AP7215-33YG-13 | DIODES | U7 | SOT-89-3 | 3.3V Positive Fixed SOT-89-3 Voltage Regulators - Linear, Low Drop Out (LDO) Regulators RoHS | YES | 2 | 0.2497 | 0.50
C2150698 | AP2191SG-13 | DIODES | U8,U9,U10,U11 | SOP-8 | 1 Active High 1.5A High Side Switch SOP-8 Power Distribution Switches, Load Drivers RoHS | YES | 10 | 0.1132 | 1.13
C207281 | SP3011-06UTG | Littelfuse | U12,U13,U14,U15 | UDFN-14(1.4x3.5) | 12.5VC Clamp 3A@8/20us Ipp ESD DIODE UDFN-14(1.4x3.5) | YES | 8 | 0.5242 | 4.19
C87572 | SPM6530T-1R0M120 | TDK | L2 | SMD,7.1x6.5mm | 13A 1uH ±20% 14.1A 7.81mΩ SMD,7.1x6.5mm Fixed Inductors RoHS | YES | 5 | 0.1767 | 0.88
C466222 | TCC0402C0G100J500AT | CCTC | C30,C31 | 0402 | 10pF ±5% 50V Ceramic Capacitor C0G 0402 | YES | 50 | 0.0034 | 0.17
C255919 | X1E0000210202 | EPSON | X1 | SMD3225-4P | Crystal 24MHz ±10ppm 9pF 40Ω SMD3225-4P | YES | 5 | 0.2546 | 1.27
C517755 | TC0250B1742TCC | UNI-ROYAL | R20 | 0402 | 17.4kΩ ±0.1% 62.5mW 0402 Thin Film Resistor | YES | 20 | 0.0225 | 0.45
C1883521 | AF0402FR-0711KL | YAGEO | R19 | 0402 | 62.5mW 11kΩ 50V Thick Film Resistor ±100ppm/℃ ±1% 0402 Chip Resistor - Surface Mount RoHS | YES | 100 | 0.005 | 0.50
C127447 | RC0603JR-0747KL | YAGEO | R18 | 0603 | 47kΩ 100mW 75V Thick Film Resistor ±100ppm/℃ ±5% 0603 Chip Resistor - Surface Mount RoHS | YES | 100 | 0.0049 | 0.49
C413078 | ERJ2RKF6800X | PANASONIC | R9 | 0402 | 100mW 680Ω Thick Film Resistor ±100ppm/℃ ±1% 0402 Chip Resistor - Surface Mount RoHS | YES | 100 | 0.0043 | 0.43
C413085 | ERJ2RKF1601X | PANASONIC | R8 | 0402 | 100mW 1.6kΩ Thick Film Resistor ±100ppm/℃ ±1% 0402 Chip Resistor - Surface Mount RoHS | YES | 100 | 0.0048 | 0.48
C14675 | RC0603FR-07100KL | YAGEO | R4,R24 | 0603 | 100mW 100kΩ 75V Thick Film Resistor ±100ppm/℃ ±1% 0603 Chip Resistor - Surface Mount RoHS | YES | 100 | 0.0047 | 0.47
C159891 | RK73B1JTTD103J | KOA | R2,R3,R5,R6,R7,R16,R23,R27,R28,R29,R30,R40 | 0603 | 100mW 10kΩ 75V Thick Film Resistor ±5% ±200ppm/℃ 0603 Chip Resistor - Surface Mount RoHS | YES | 100 | 0.004 | 0.40
C95177 | RC0603JR-070RL | YAGEO | R1,R12,R13,R14,R15 | 0603 | 100mW 0Ω 75V Thick Film Resistor ±5% 0603 Chip Resistor - Surface Mount RoHS | YES | 100 | 0.0034 | 0.34
C142600 | SI4134DY-T1-GE3 | VISHAY | Q5 | SO-8 | N-Channel 30V 14A 5W Surface Mount SO-8 | YES | 5 | 0.2764 | 1.38
C151586 | DMT6016LSS-13 | DIODES | Q4 | SO-8 | N-Channel 60V 9.2A 2.1W Surface Mount SO-8 | YES | 2 | 0.7893 | 1.58
C111700 | 2SC4081T106R | ROHM | Q2 | SC-70(SOT-323) | Bipolar (BJT) Transistor NPN 50V 150mA 180MHz 200mW Surface Mount SC-70(SOT-323) | YES | 20 | 0.0412 | 0.82
C111698 | 2SA1576AT106R | ROHM | Q1 | SC-70(SOT-323) | Bipolar (BJT) Transistor PNP 50V 150mA 140MHz 200mW Surface Mount SC-70(SOT-323) | YES | 20 | 0.0291 | 0.58
C909806 | DFE252012F-1R5M=P2 | muRata | L3 | 1008 | 2.7A 1.5uH ±20% 58mΩ 3.8A 1008 Fixed Inductors RoHS | YES | 5 | 0.142 | 0.71
C2045037 | SRU8043-3R9Y | BOURNS | L1 | SMD,8x8mm | 4.8A 3.9uH ±30% 14.6mΩ 4A Magnetic Shielded Inductor SMD,8x8mm Fixed Inductors RoHS | YES | 2 | 1.201 | 2.40
C6376748 | 484050001 | MOLEX | J2,J3,J4,J5 | Through Hole | Through Hole USB, DVI, HDMI Connector Assemblies RoHS | YES | 6 | 3.1262 | 18.76
C355375 | UPD720201K8-701-BAC-A | RENESAS |  | QFN-68-EP(8x8) | USB to PCI Express 4 5Gbps QFN-68-EP(8x8) Controllers | NO | 5 | 3.0081 | 15.04 | 2026-09-07 |  | 26+

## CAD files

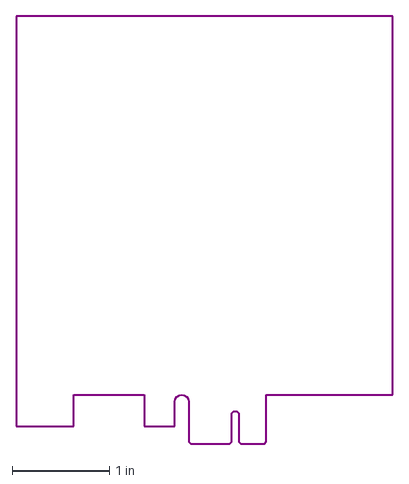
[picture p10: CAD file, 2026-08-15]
2D/UNG8315_D_EDGE_Only_Short.dxf
3.87 x 4.39 in

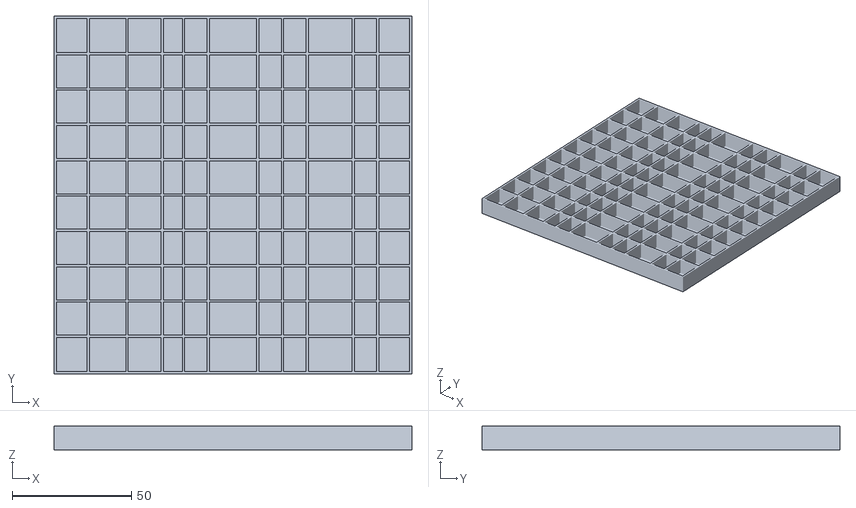
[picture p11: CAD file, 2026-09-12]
3D/Assembly/box_150x150x10.stl
150.0 x 150.0 x 10.0

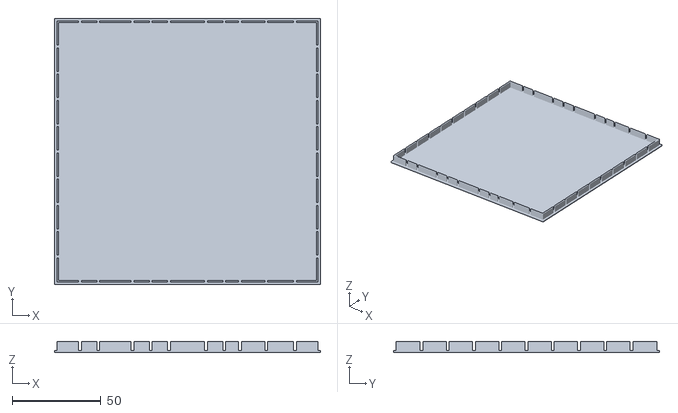
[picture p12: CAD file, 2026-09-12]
3D/Assembly/lid_150x150x10.stl
150.0 x 150.0 x 6.00

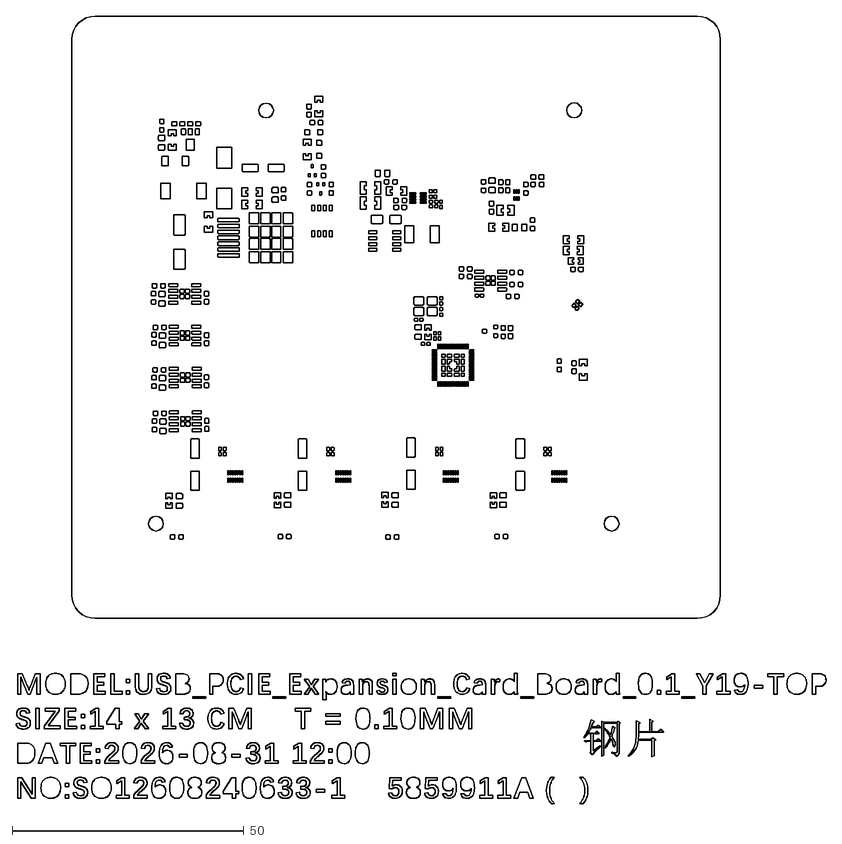
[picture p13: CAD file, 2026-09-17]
production/JLCPCB_Stencil_Verification_V0-1/SO12608240633-1.DXF
174.8 x 170.0

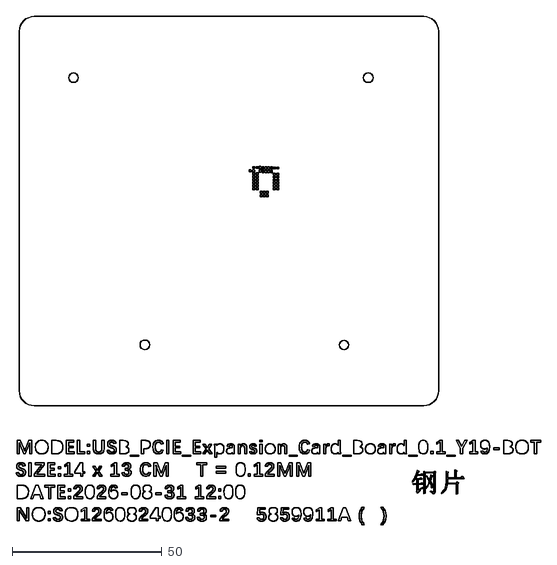
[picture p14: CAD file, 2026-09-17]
production/JLCPCB_Stencil_Verification_V0-1/SO12608240633-2.DXF
175.1 x 169.7

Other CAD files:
3D/PCB_Render.blend

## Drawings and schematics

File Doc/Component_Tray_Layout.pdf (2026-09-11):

1 | 2 | 3 | 4 | 5 | 6 | 7 | 8 | 9 | 10 | 11
12 | 13 | 14 | 15 | 16 | 17 | 18 | 19 | 20 | 21 | 22
23 | 24 | 25 | 26 | 27 | 28 | 29 | 30 | 31 | 32 | 33
34 | 35 | 36 | 37 | 38 | 39 | 40 | 41 | 42 | 43 | 44
45 | 46 | 47 | 48 | 49 | 50 | 51 | 52 | 53 ⚠ | 54 | 55

56
- | · | · | · | · | · | · | · | · | ·
- | · | · | · | · | · | · | · | · | · | ·
- | · | · | · | · | · | · | · | · | · | ·
- | · | · | · | · | · | · | · | · | · | ·
- | · | · | · | · | · | · | · | · | · | ·
- | · | · | · | · | · | · | · | · | · | ·

# Component Tray Layout

## USB PCIe Expansion Card · Rev 0.1

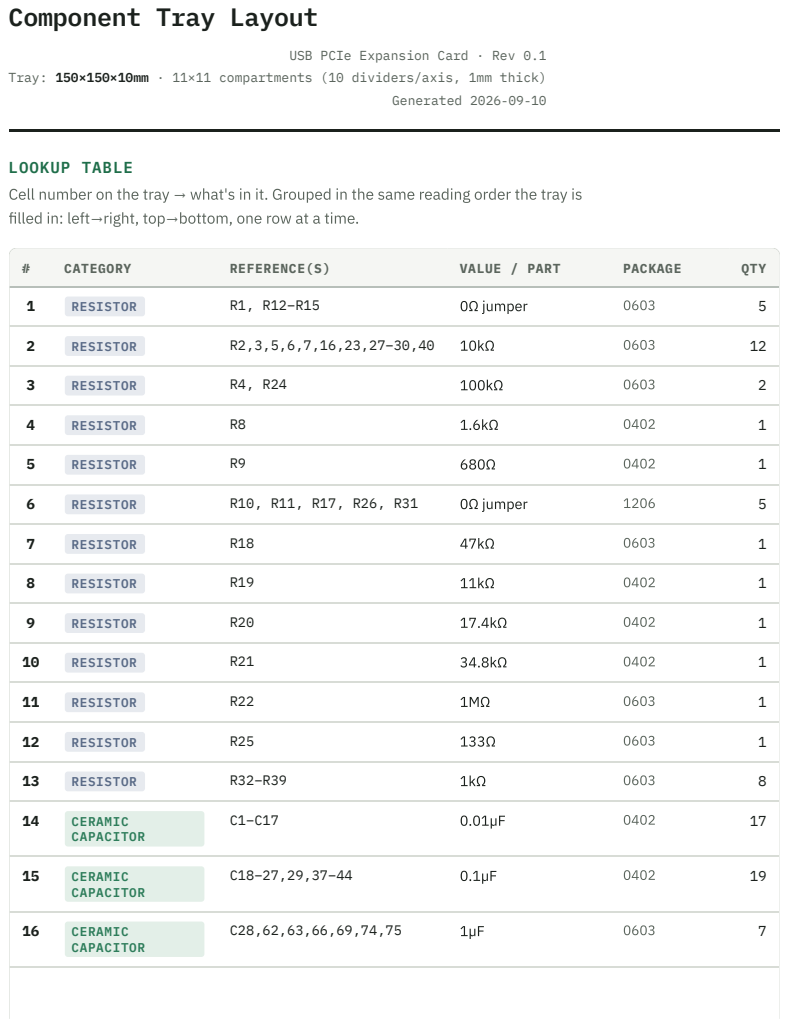
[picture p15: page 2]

Tray: 150×150×10mm · 11×11 compartments (10 dividers/axis, 1mm thick)

Cell number on the tray → what's in it. Grouped in the same reading order the tray is

filled in: left→right, top→bottom, one row at a time.

# | CATEGORY | REFERENCE(S) | VALUE / PART | PACKAGE | QTY

## 17 CERAMIC

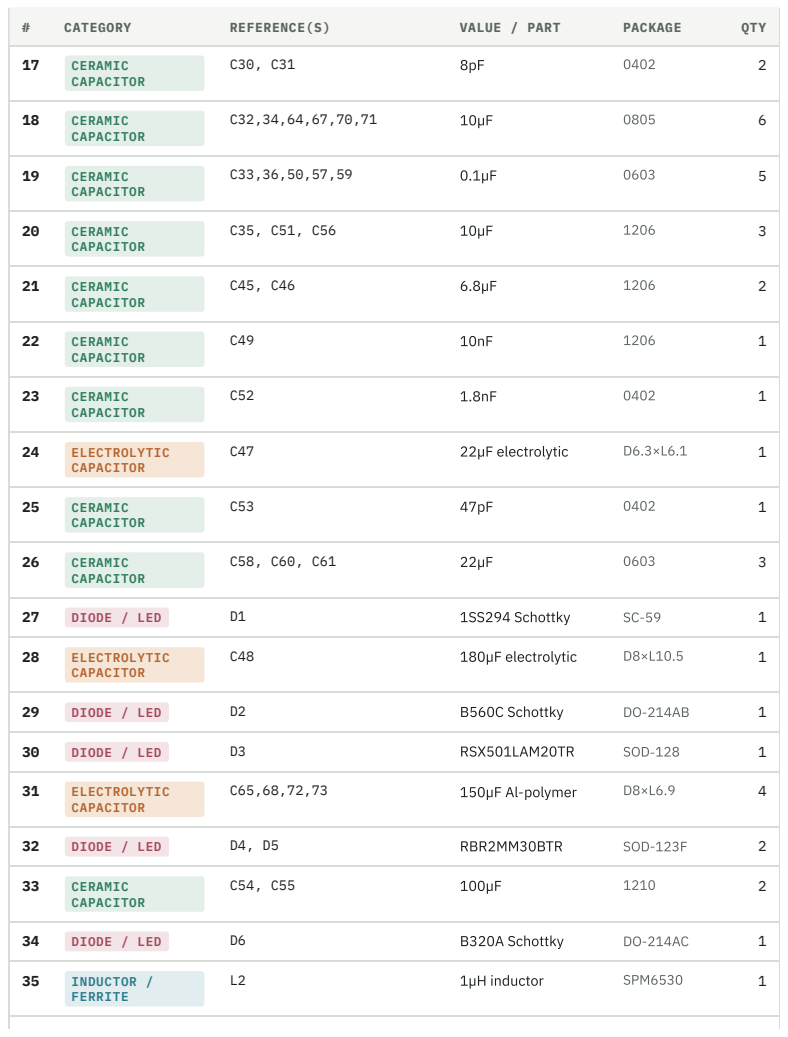
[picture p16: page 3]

## 39 INDUCTOR / FERRITE

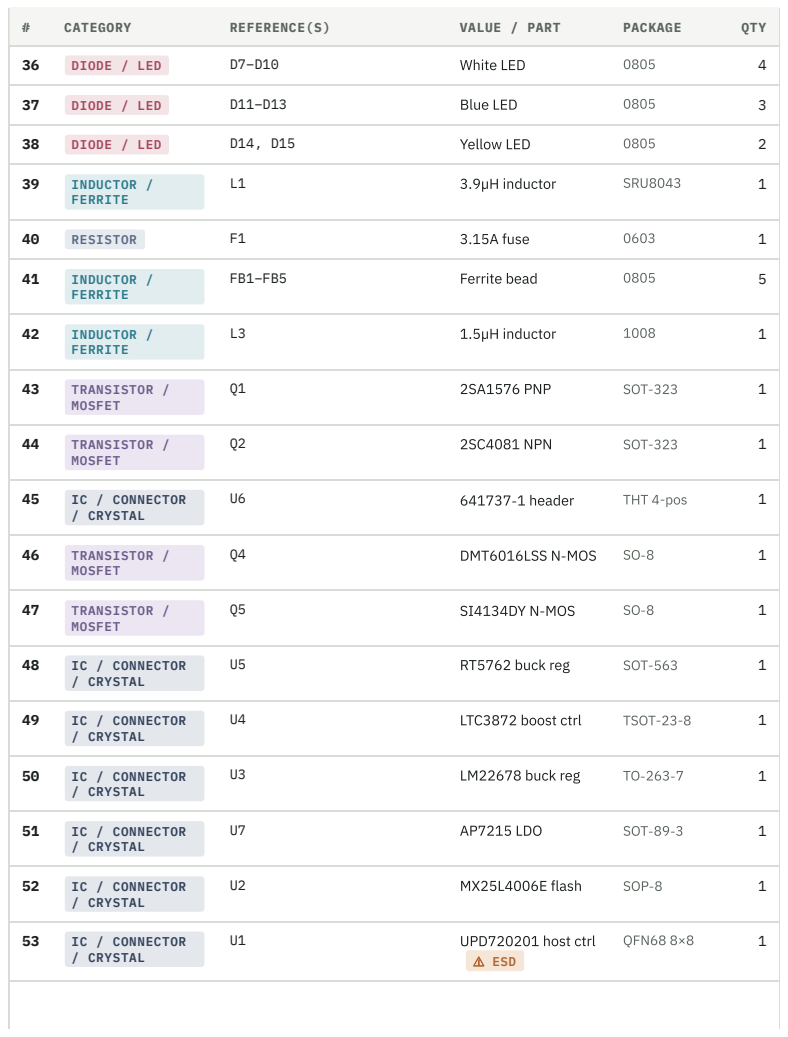
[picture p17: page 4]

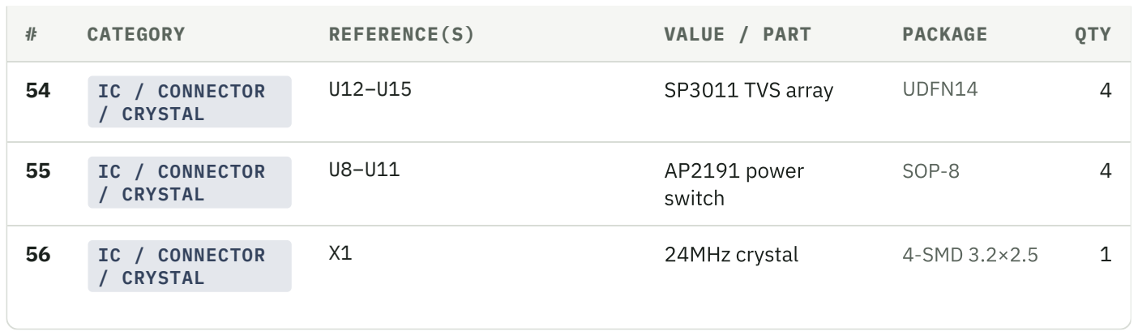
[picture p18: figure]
54 IC / CONNECTOR / CRYSTAL; SP3011 TVS array; UDFN14; 55 IC / CONNECTOR / CRYSTAL; AP2191 power; switch; SOP‑8; 56 IC / CONNECTOR / CRYSTAL; 24MHz crystal; 4‑SMD 3.2×2.5
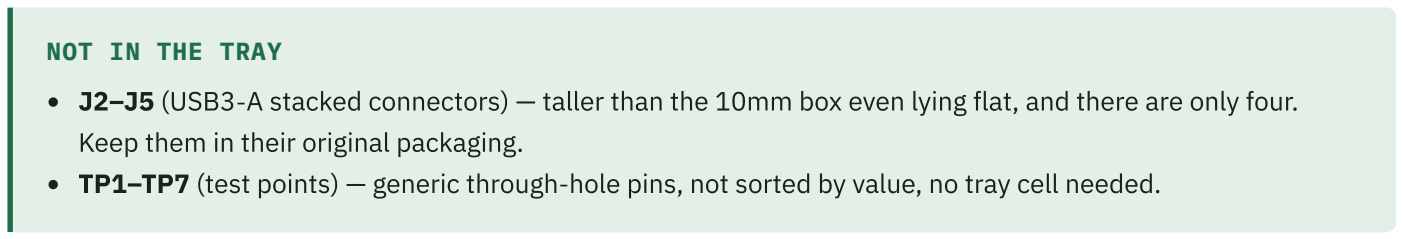
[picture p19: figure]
NOT IN THE TRAY; Keep them in their original packaging.

J2–J5 (USB3‑A stacked connectors) — taller than the 10mm box even lying flat, and there are only four.

TP1–TP7 (test points) — generic through‑hole pins, not sorted by value, no tray cell needed.

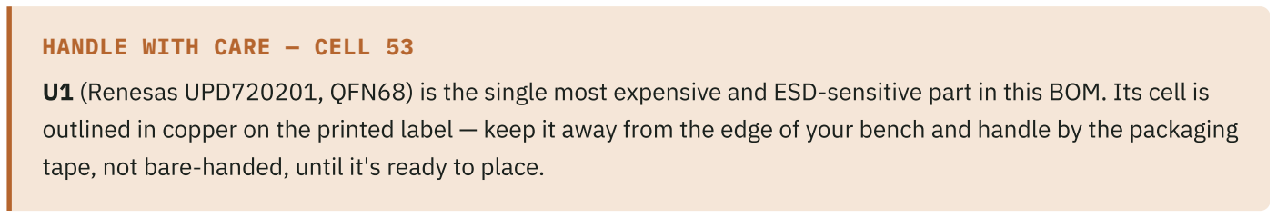
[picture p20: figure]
HANDLE WITH CARE — CELL 53

U1 (Renesas UPD720201, QFN68) is the single most expensive and ESD‑sensitive part in this BOM. Its cell is

outlined in copper on the printed label — keep it away from the edge of your bench and handle by the packaging tape, not bare‑handed, until it's ready to place.

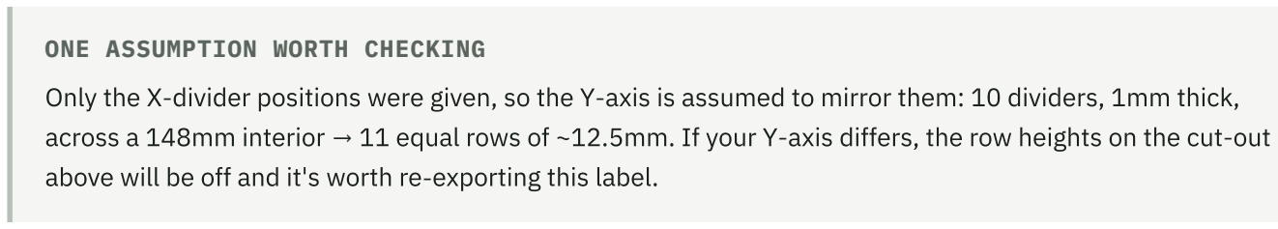
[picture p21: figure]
ONE ASSUMPTION WORTH CHECKING

Only the X‑divider positions were given, so the Y‑axis is assumed to mirror them: 10 dividers, 1mm thick,

across a 148mm interior → 11 equal rows of ~12.5mm. If your Y‑axis differs, the row heights on the cut‑out

above will be off and it's worth re‑exporting this label.

USB_PCIE_Board · Doc/Component_Tray_Layout | 56 BOM groups placed of 121 compartments

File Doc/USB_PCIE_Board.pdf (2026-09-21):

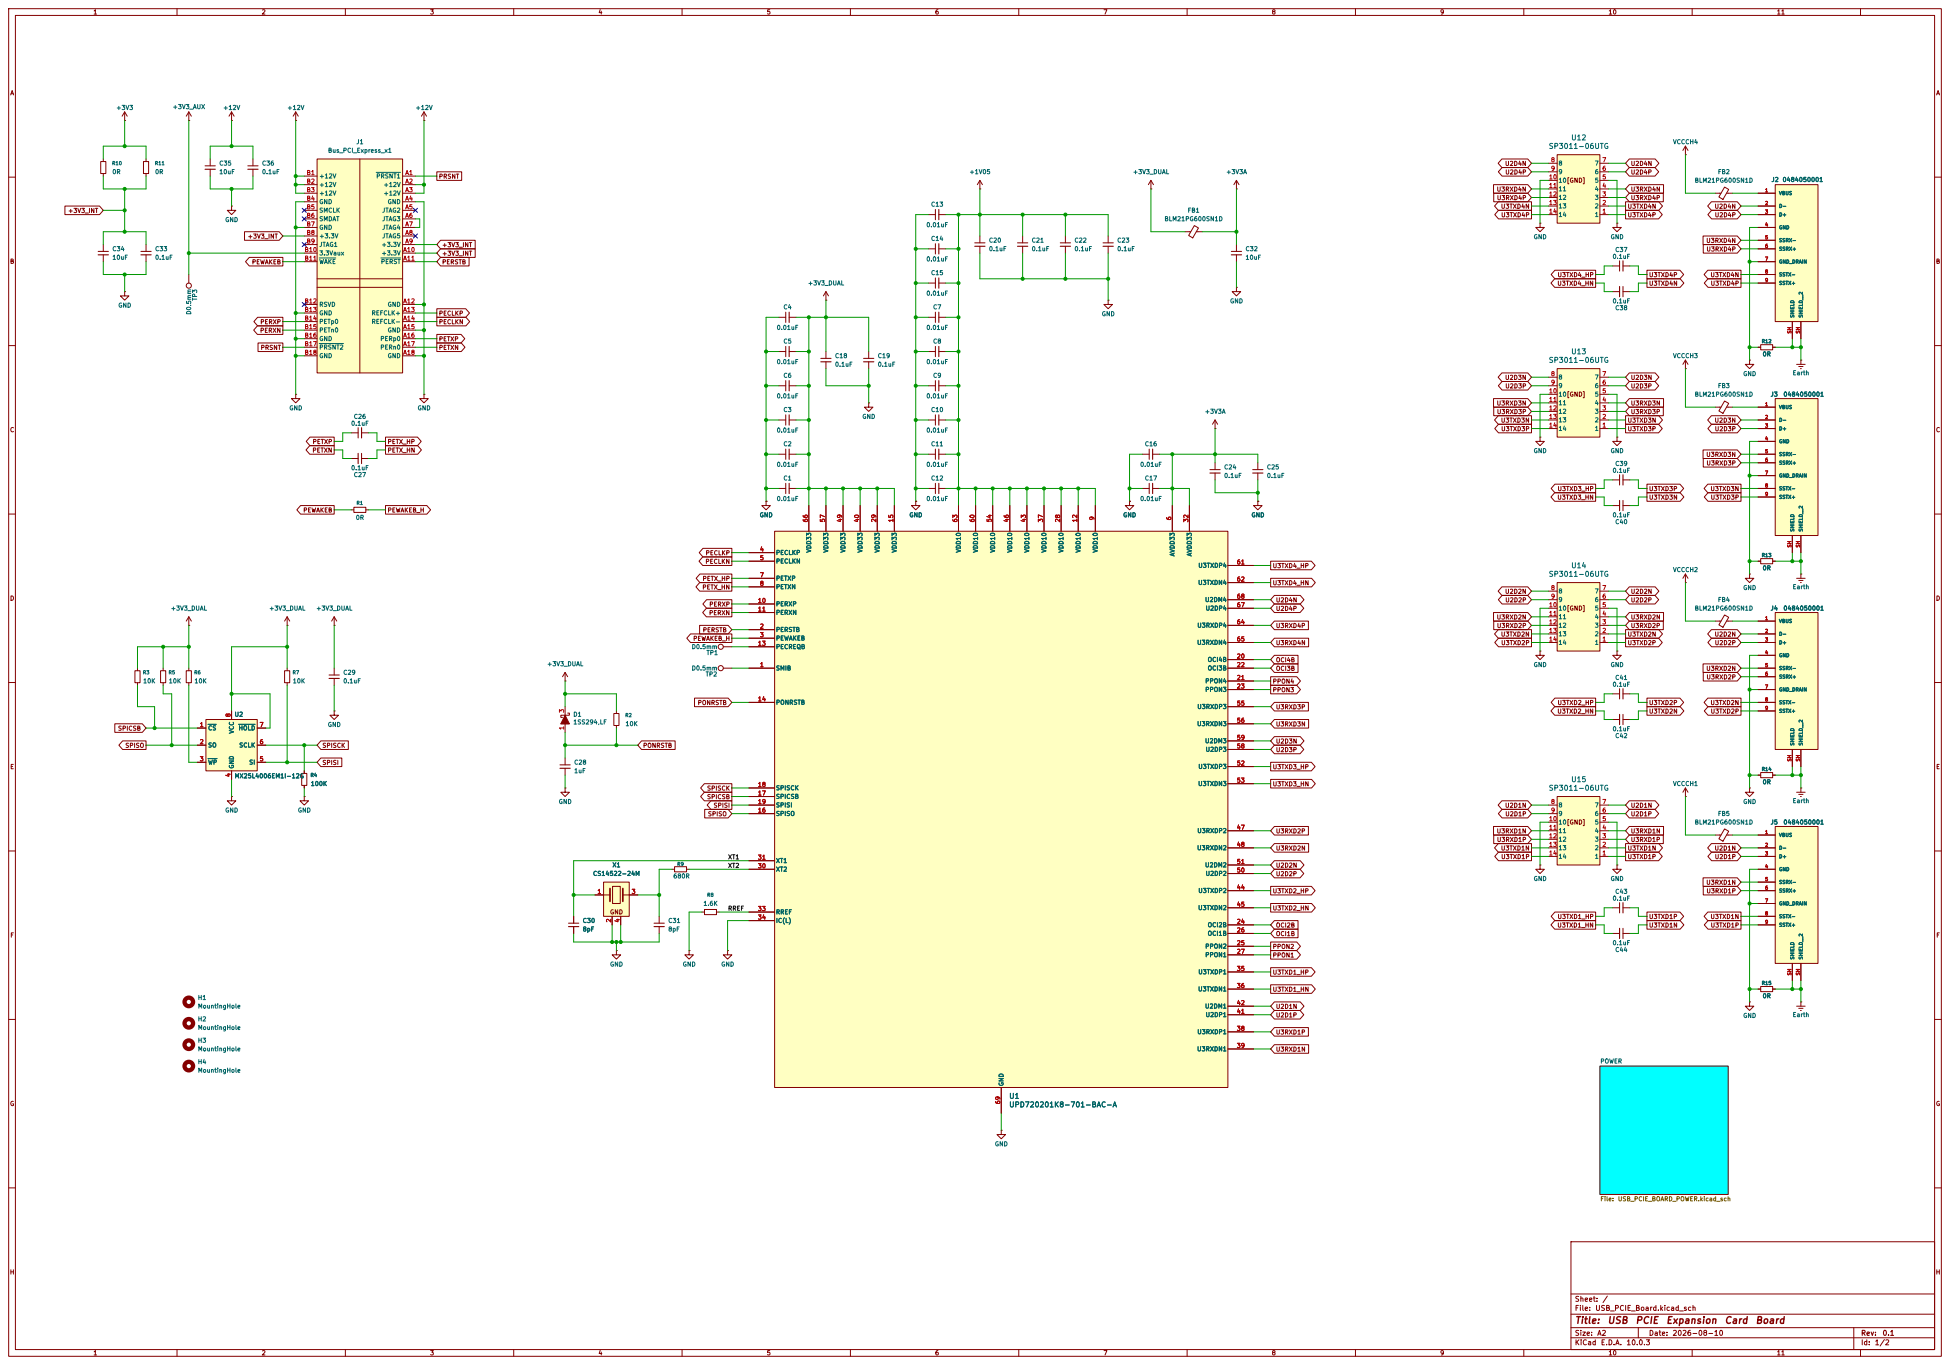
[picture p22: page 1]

3.3Vaux B10 WAKE B11 RSVD B12 GND B13 PETp0 B14 PETn0 B15 GND B16 PRSNT2 B17 GND B18

Sheet: /
File: USB_PCIE_Board.kicad_sch
Title: USB PCIE Expansion Card Board

Size: A2 | Rev: 0.1
KiCad E.D.A. 10.0.3 | Id: 1/2

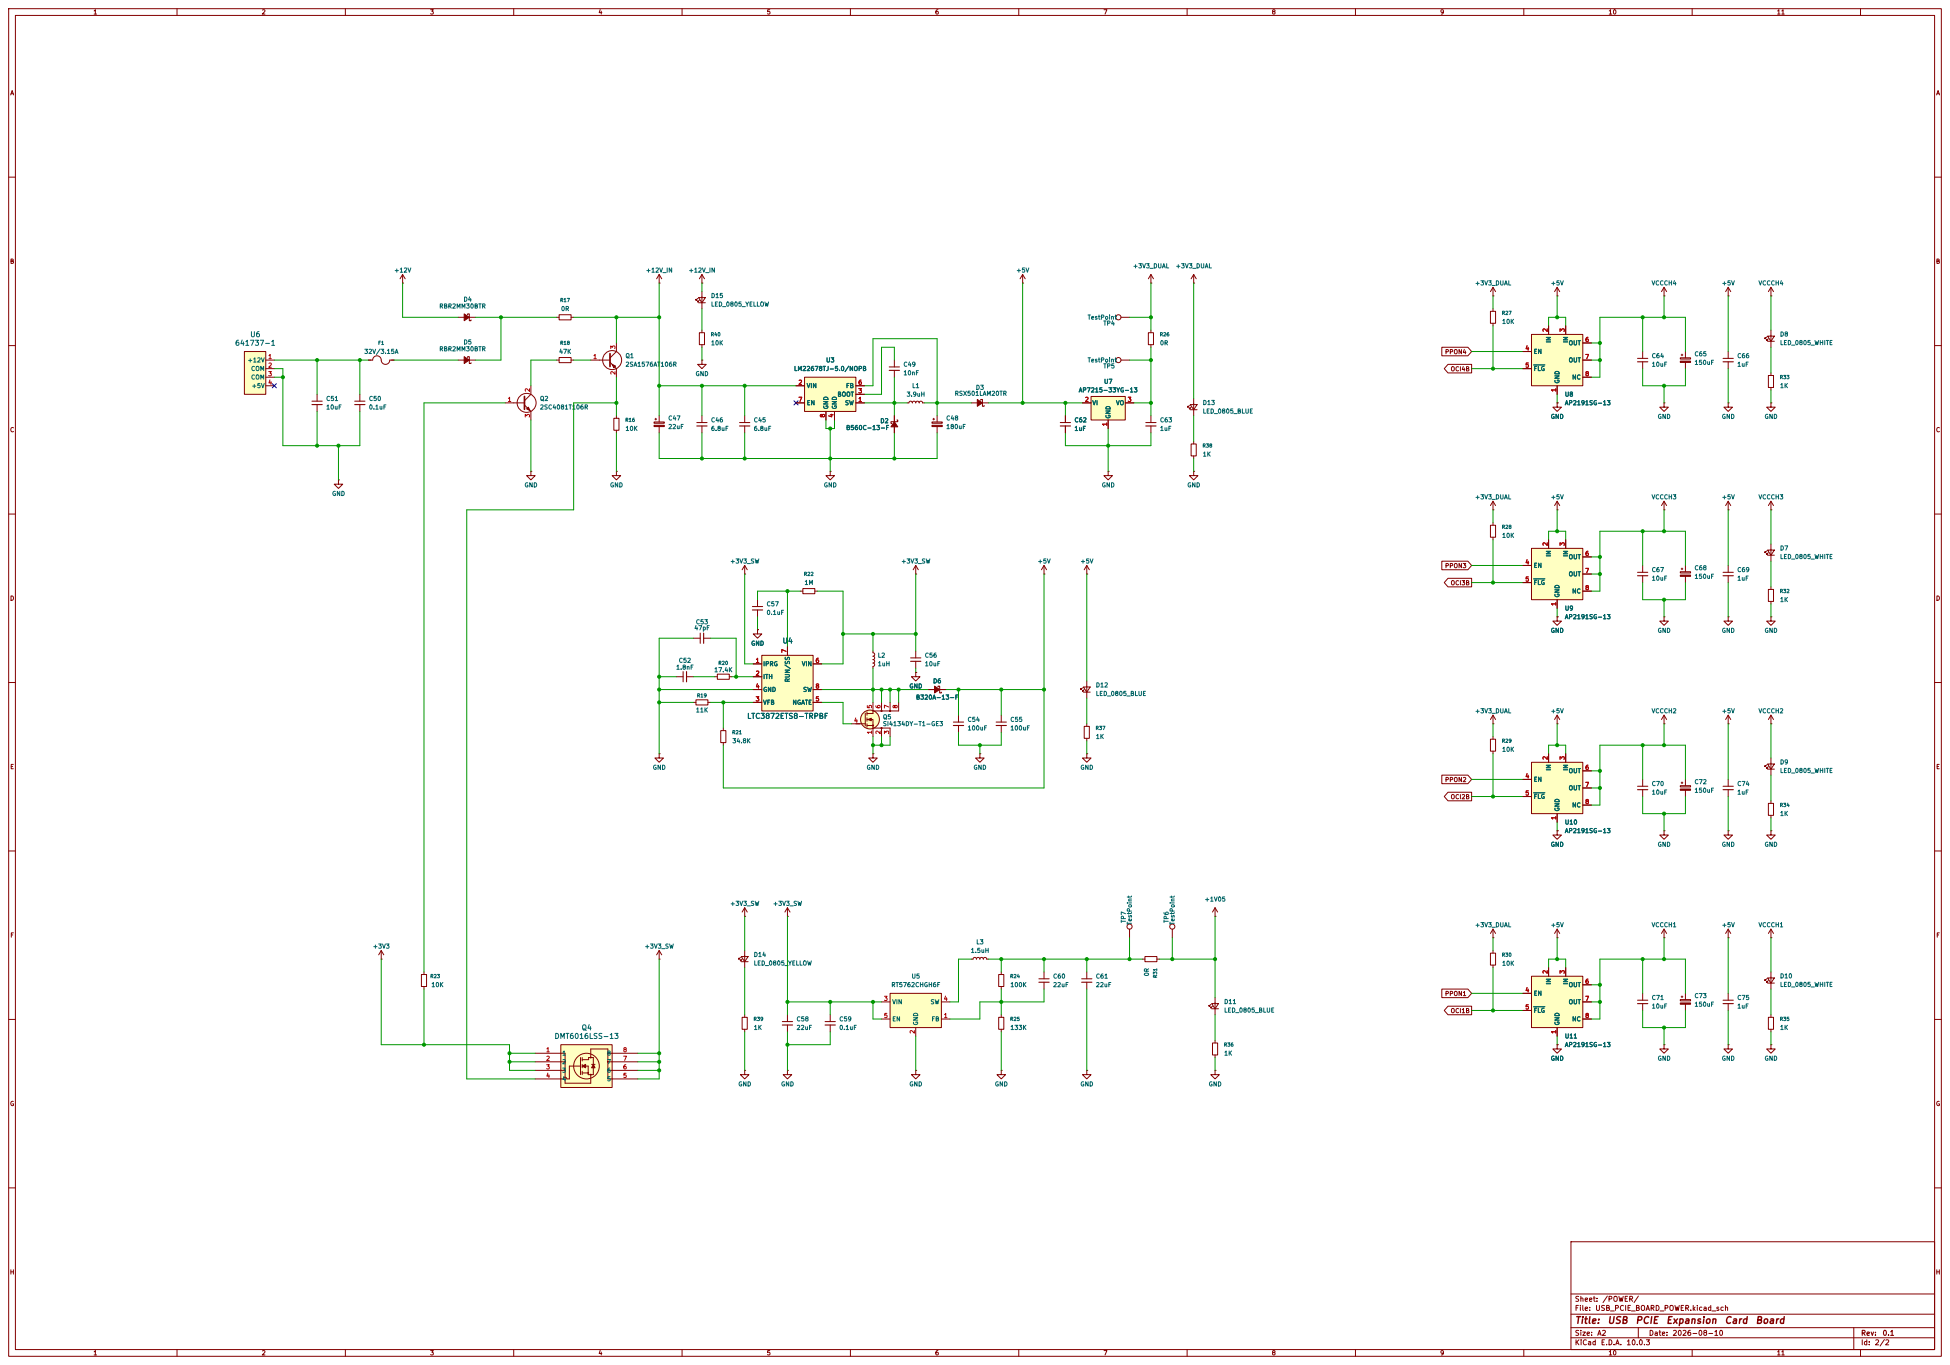
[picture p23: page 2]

Sheet: /POWER/
File: USB_PCIE_BOARD_POWER.kicad_sch
Title: USB PCIE Expansion Card Board

Size: A2 | Rev: 0.1
KiCad E.D.A. 10.0.3 | Id: 2/2

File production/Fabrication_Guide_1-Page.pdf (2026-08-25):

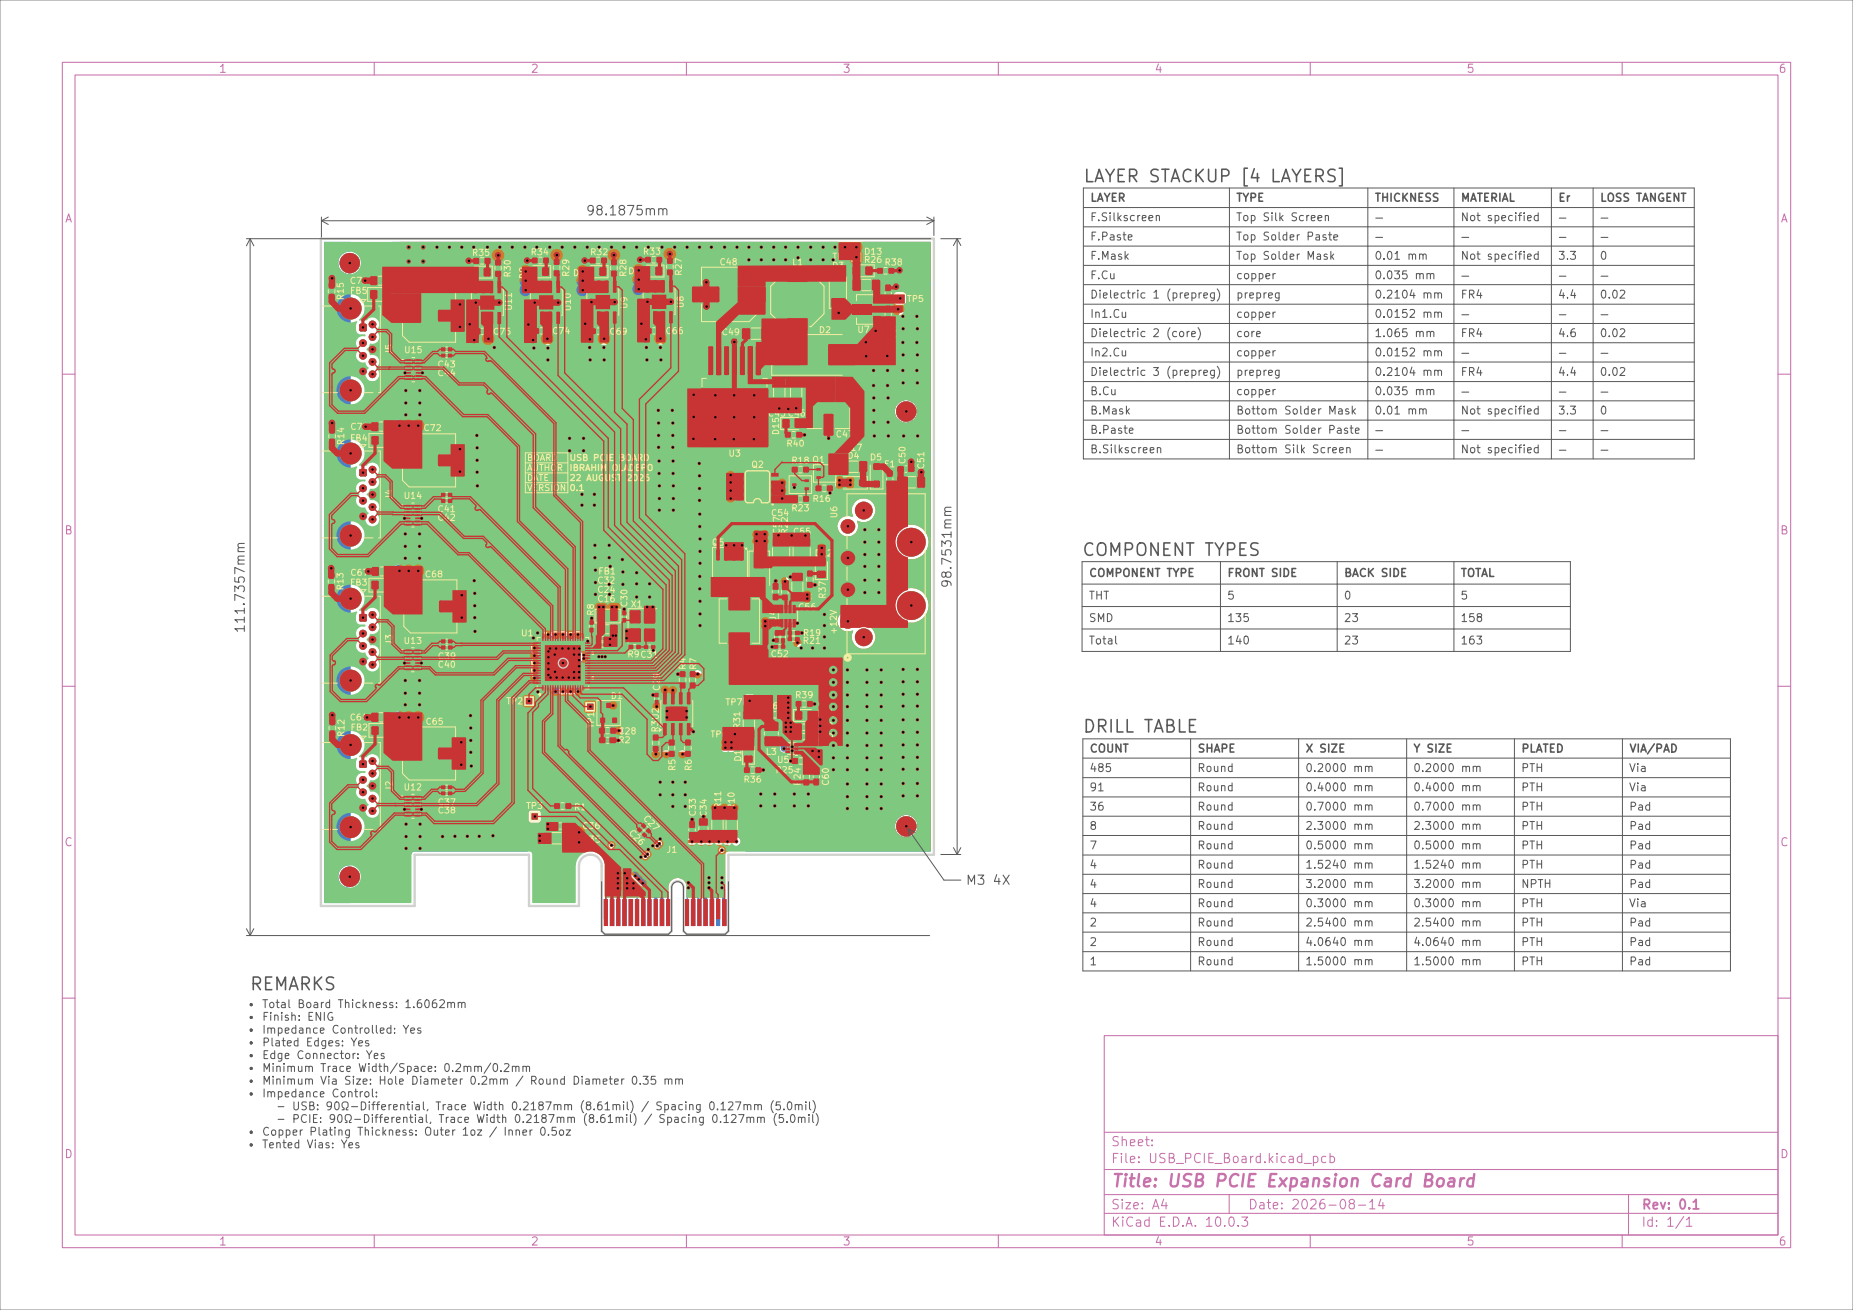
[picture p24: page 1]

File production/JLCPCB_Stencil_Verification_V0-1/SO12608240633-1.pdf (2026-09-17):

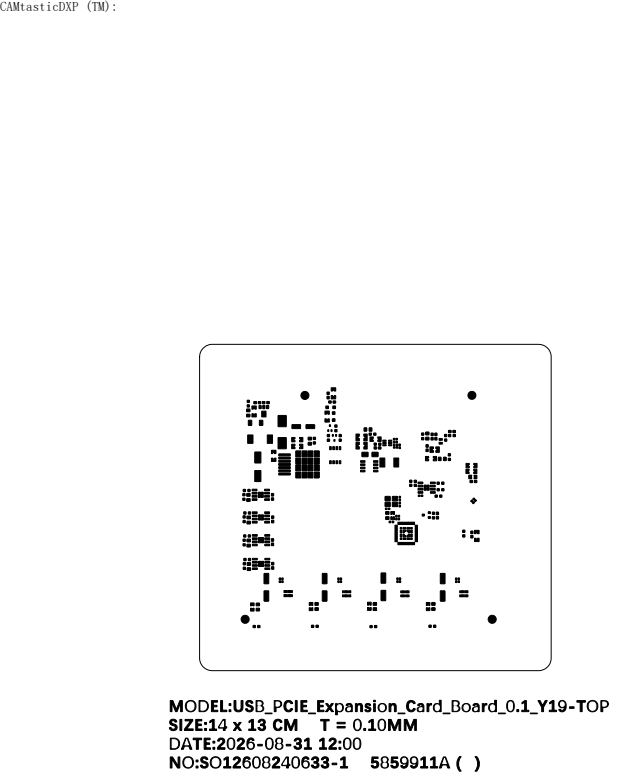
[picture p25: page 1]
CAMtasticDXP (TM):

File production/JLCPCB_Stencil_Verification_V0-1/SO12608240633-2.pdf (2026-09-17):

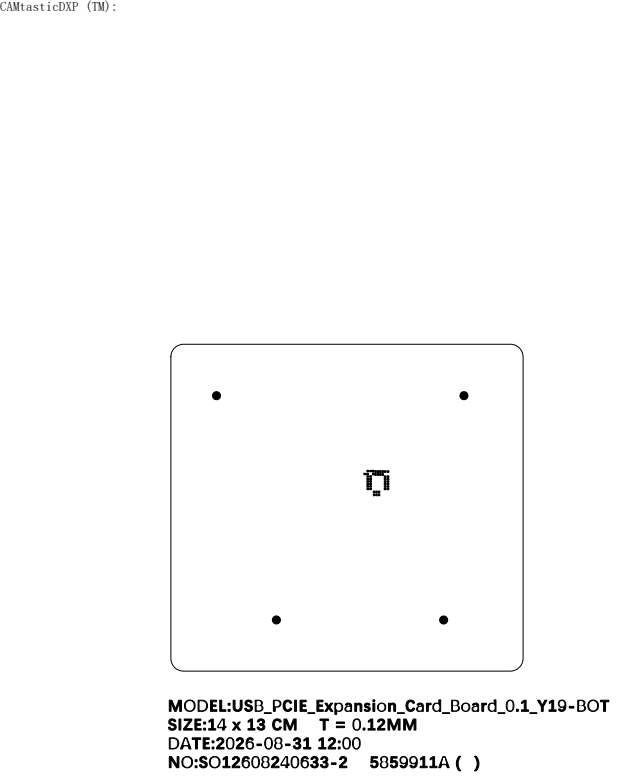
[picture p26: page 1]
CAMtasticDXP (TM):

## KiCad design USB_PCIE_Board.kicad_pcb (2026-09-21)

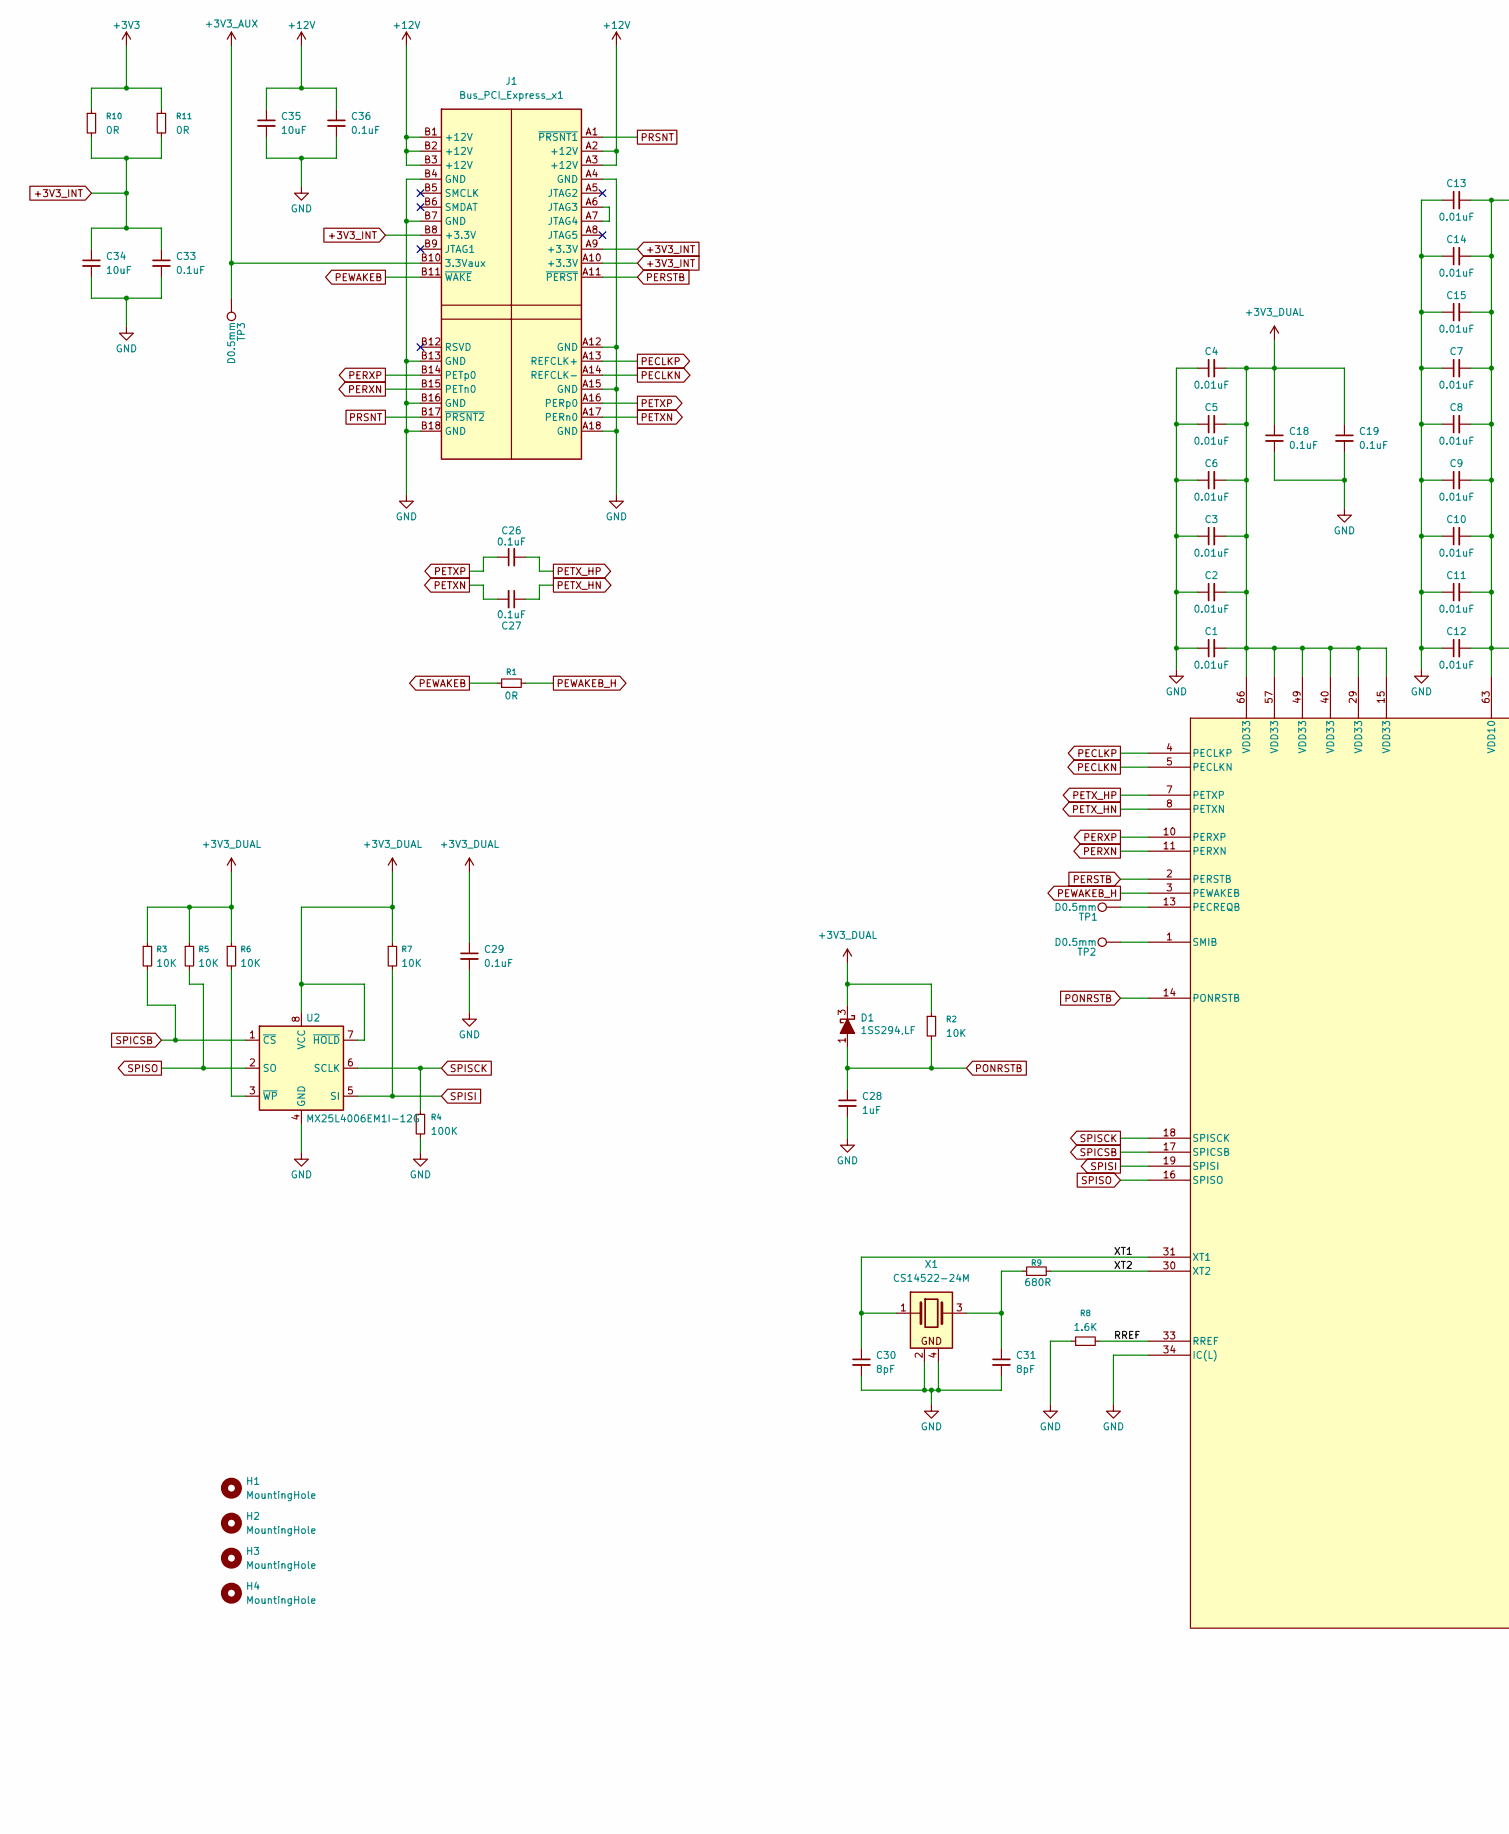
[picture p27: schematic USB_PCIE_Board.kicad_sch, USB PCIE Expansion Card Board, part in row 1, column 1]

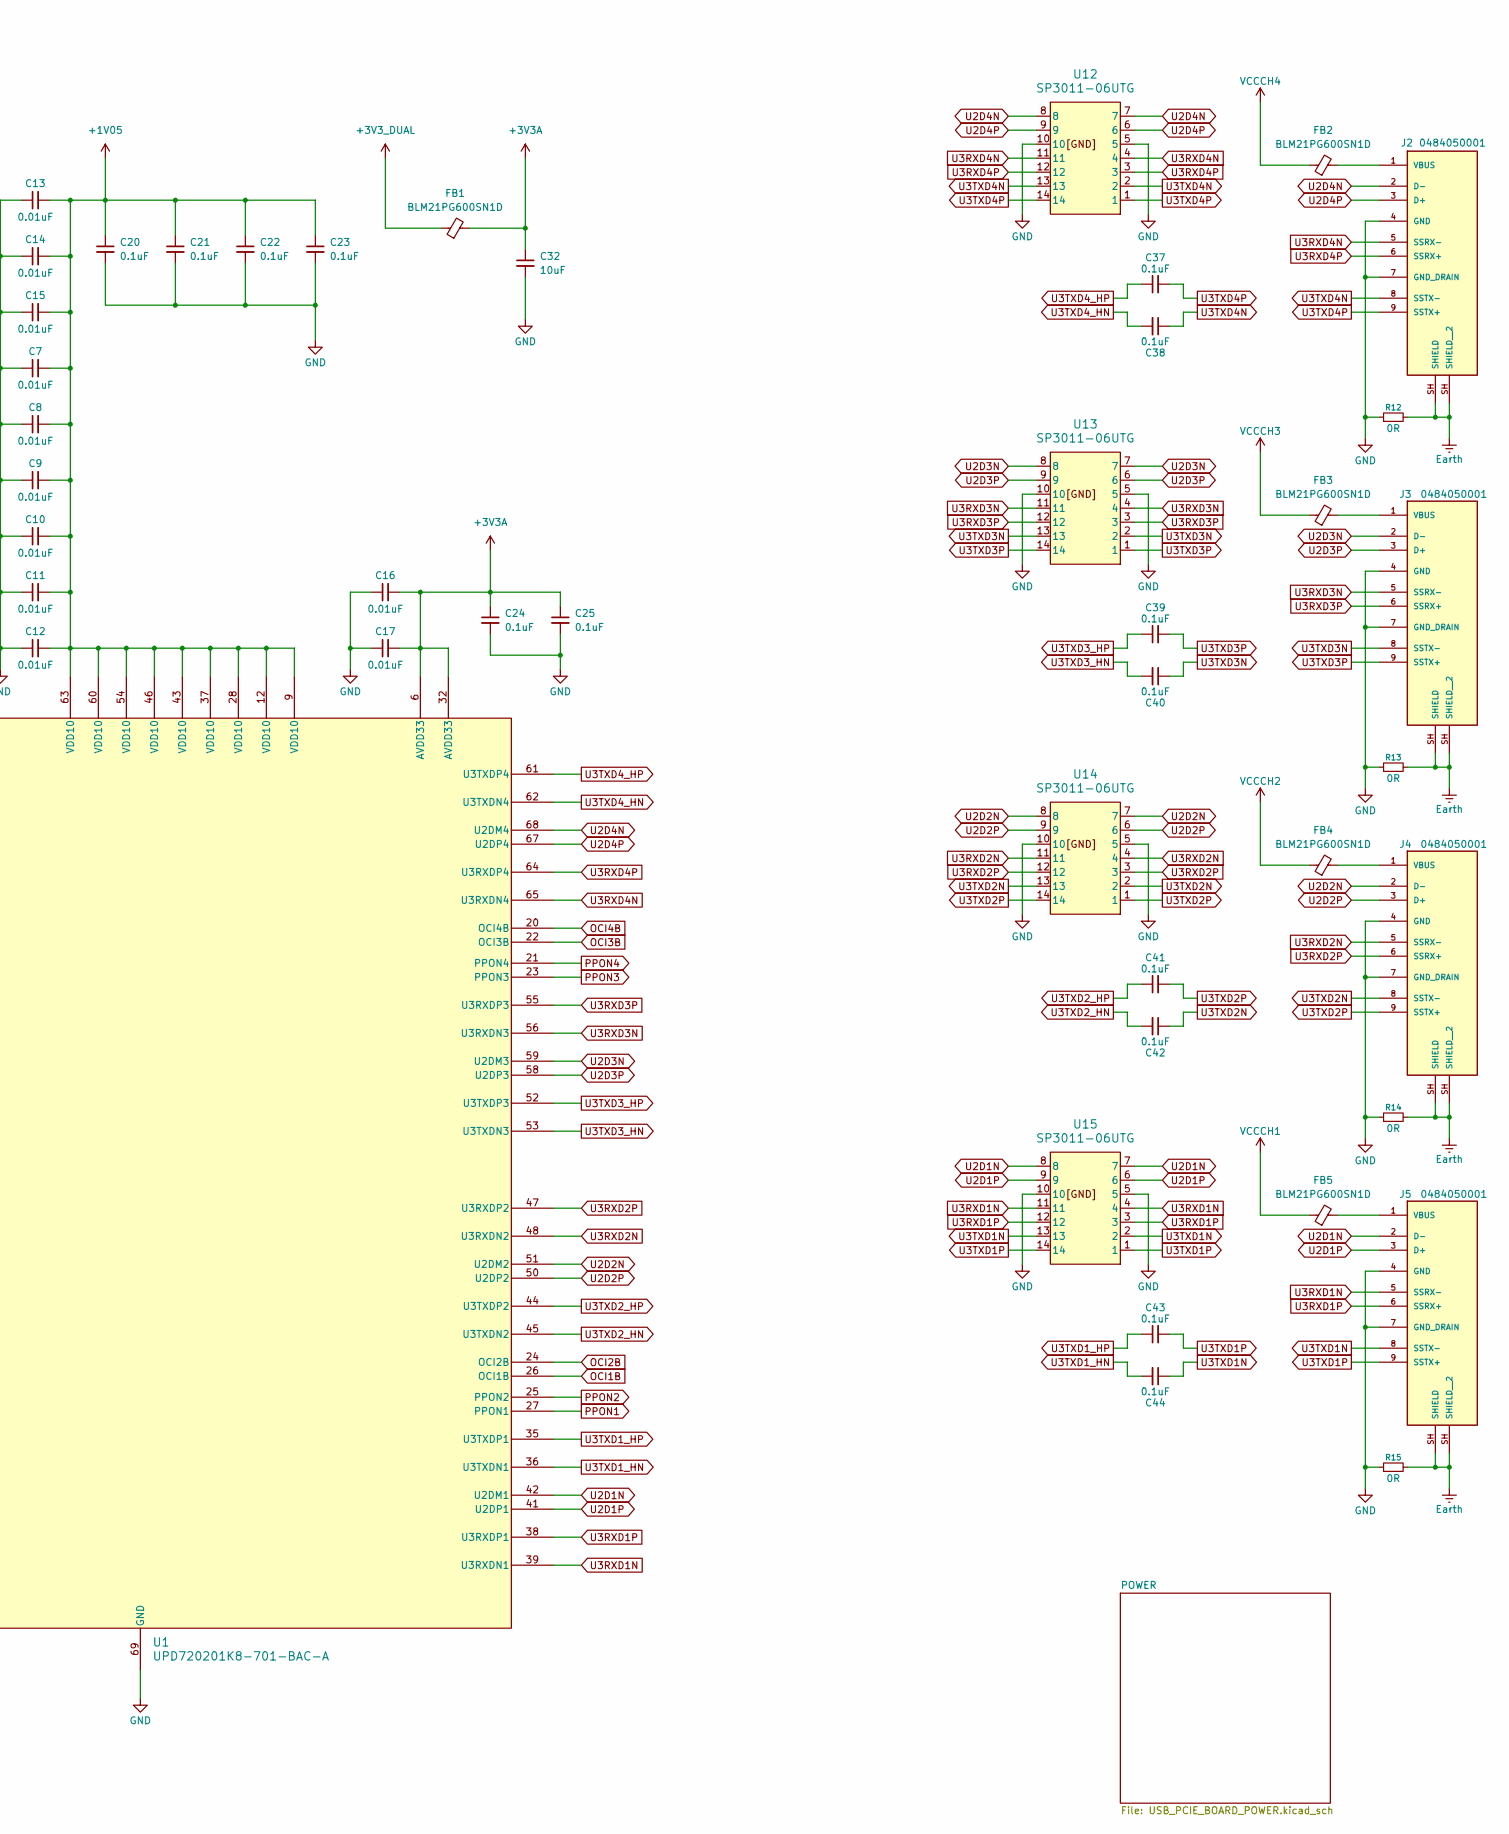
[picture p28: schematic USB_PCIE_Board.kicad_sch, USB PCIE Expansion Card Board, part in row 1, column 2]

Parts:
C1, C2, C3, C4, C5, C6, C7, C8, C9, C10, C11, C12, C13, C14, C15, C16, C17: 0.01uF; C_0402_1005Metric_Pad0.74x0.62mm_HandSolder; Manufacturer Part # CC0402KRX7R9BB103; DigiKey Part # 311-1349-1-ND
C18, C19, C20, C21, C22, C23, C24, C25, C26, C27, C29, C37, C38, C39, C40, C41, C42, C43, C44: 0.1uF; C_0402_1005Metric_Pad0.74x0.62mm_HandSolder; Voltage Rating 16V; Manufacturer Part # CC0402KRX7R7BB104; DigiKey Part # C60474
C28: 1uF; C_0603_1608Metric_Pad1.08x0.95mm_HandSolder; Voltage Rating 25V; Manufacturer Part # CL10B105KA8NNNC; DigiKey Part # 1276-1184-1-ND
C30, C31: 8pF; C_0402_1005Metric_Pad0.74x0.62mm_HandSolder; Voltage Rating 50V; Manufacturer Part # GJM1555C1H8R0DB01D; DigiKey Part # 490-GJM1555C1H8R0DB01DCT-ND
C32, C34: 10uF; C_0805_2012Metric_Pad1.18x1.45mm_HandSolder; Voltage Rating 16V; Manufacturer Part # CC0805KKX7R7BB106; DigiKey Part # 311-3501-1-ND
C33, C36: 0.1uF; C_0603_1608Metric_Pad1.08x0.95mm_HandSolder; Voltage Rating 50V; Manufacturer Part # CC0603KRX7R9BB104; DigiKey Part # C14663
C35: 10uF; C_1206_3216Metric_Pad1.33x1.80mm_HandSolder; Voltage Rating 25V; Manufacturer Part # GRM319R61E106KA12D; DigiKey Part # 490-5525-1-ND
D1: 1SS294,LF; SC-59; Manufacturer Part # 1SS294,LF; DigiKey Part # 1SS294LFCT-ND
FB1, FB2, FB3, FB4, FB5: BLM21PG600SN1D; Ferrite_0805_2012Metric_BigPads; Manufacturer Part # BLM21PG600SN1D; DigiKey Part # 490-1053-1-ND
H1, H2, H3, H4: MountingHole; MountingHole_3.2mm_M3
J1: Bus_PCI_Express_x1; BUS_PCIexpress_x1
J2, J3, J4, J5: 0484050001; USB3_A_Molex_48406-0001_Horizontal_Stacked; Manufacturer Part # 0484050001; DigiKey Part # 0484050001-ND
R1, R12, R13, R14, R15: 0R; R_0603_1608Metric_Pad0.98x0.95mm_HandSolder; Manufacturer Part # RC0603JR-070RL; DigiKey Part # 311-0.0GRCT-ND
R2, R3, R5, R6, R7: 10K; R_0603_1608Metric_Pad0.98x0.95mm_HandSolder; Tolerance 5%; Manufacturer Part # RK73B1JTTD103J; DigiKey Part # 2019-RK73B1JTTD103JCT-ND
R4: 100K; R_0603_1608Metric_Pad0.98x0.95mm_HandSolder; Tolerance 1%; Manufacturer Part # RC0603FR-07100KL; DigiKey Part # 311-100KHRCT-ND
R8: 1.6K; R_0402_1005Metric_Pad0.72x0.64mm_HandSolder; Tolerance 1%; Manufacturer Part # ERJ-2RKF1601X; DigiKey Part # P1.60KLCT-ND
R9: 680R; R_0402_1005Metric_Pad0.72x0.64mm_HandSolder; Manufacturer Part # ERJ2RKF6800X; DigiKey Part # 10-ERJ-H2RF6800XCT-ND
R10, R11: 0R; R_1206_3216Metric_Pad1.30x1.75mm_HandSolder; Manufacturer Part # RK73Z2BTTD; DigiKey Part # 2019-RK73Z2BTTDCT-ND
TP1, TP2, TP3: D0.5mm; TestPoint_THTPad_1.0x1.0mm_Drill0.5mm
U1: UPD720201K8-701-BAC-A; QFN68_8X8_REN-M; Manufacturer Part # UPD720201K8-701-BAC-A; DigiKey Part # UPD720201K8-701-BAC-A-ND
U2: MX25L4006EM1I-12G; HSOP-8-1EP_3.9x4.9mm_P1.27mm_EP2.3x2.3mm_FLASH; Manufacturer Part # MX25L4006EM1I-12G; DigiKey Part # 1092-1114-ND
U12, U13, U14, U15: SP3011-06UTG; SON14_SP3011-06UTG_LTF-M; Manufacturer Part # SP3011-06UTG; DigiKey Part # F3579CT-ND
X1: CS14522-24M; Crystal_SMD_3225-4Pin_3.2x2.5mm_HandSoldering; Manufacturer Part # CS14522-24M; DigiKey Part # 644-CS14522-24MCT-ND

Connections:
+1V05: C7.2, C8.2, C9.2, C10.2, C11.2, C12.2, C13.2, C14.2, C15.2, C20.1, C21.1, C22.1, C23.1, U1.9 (VDD10), U1.12 (VDD10), U1.28 (VDD10), U1.37 (VDD10), U1.43 (VDD10), U1.46 (VDD10), U1.54 (VDD10), U1.60 (VDD10), U1.63 (VDD10); also elsewhere on the board
+3V3: R10.1, R11.1; also elsewhere on the board
+3V3A: C16.2, C17.2, C24.1, C25.1, C32.1, FB1.2, U1.6 (AVDD33), U1.32 (AVDD33)
+3V3_AUX: J1.B10 (3.3Vaux), TP3.1 (1_1)
+3V3_DUAL: C1.2, C2.2, C3.2, C4.2, C5.2, C6.2, C18.1, C19.1, C29.1, D1.3 (K), FB1.1, R2.1, R3.1, R5.1, R6.1, R7.1, U1.15 (VDD33), U1.29 (VDD33), U1.40 (VDD33), U1.49 (VDD33), U1.57 (VDD33), U1.66 (VDD33), U2.7 (~HOLD), U2.8 (VCC); also elsewhere on the board
+3V3_INT: C33.1, C34.1, J1.A9 (+3.3V), J1.A10 (+3.3V), J1.B8 (+3.3V), R10.2, R11.2
+12V: C35.1, C36.1, J1.A2 (+12V), J1.A3 (+12V), J1.B1 (+12V), J1.B2 (+12V), J1.B3 (+12V); also elsewhere on the board
/RREF: R8.2, U1.33 (RREF)
/XT1: C30.1, U1.31 (XT1), X1.1
/XT2: R9.2, U1.30 (XT2)
Earth: J2.SH (SHIELD), J3.SH (SHIELD), J4.SH (SHIELD), J5.SH (SHIELD), R12.2, R13.2, R14.2, R15.2
GND: C1.1, C2.1, C3.1, C4.1, C5.1, C6.1, C7.1, C8.1, C9.1, C10.1, C11.1, C12.1, C13.1, C14.1, C15.1, C16.1, C17.1, C18.2, C19.2, C20.2, C21.2, C22.2, C23.2, C24.2, C25.2, C28.2, C29.2, C30.2, C31.2, C32.2, C33.2, C34.2, C35.2, C36.2, J1.A4 (GND), J1.A12 (GND), J1.A15 (GND), J1.A18 (GND), J1.B4 (GND), J1.B7 (GND), J1.B13 (GND), J1.B16 (GND), J1.B18 (GND), J2.4 (GND), J2.7 (GND_DRAIN), J3.4 (GND), J3.7 (GND_DRAIN), J4.4 (GND), J4.7 (GND_DRAIN), J5.4 (GND), J5.7 (GND_DRAIN), R4.2, R8.1, R12.1, R13.1, R14.1, R15.1, U1.34 (IC(L)), U1.69 (GND), U2.4 (GND), U12.5, U12.10, U13.5, U13.10, U14.5, U14.10, U15.5, U15.10, X1.2, X1.4; also elsewhere on the board
unnamed: C31.1, R9.1, X1.3
unnamed: J1.A6 (JTAG3), J1.A7 (JTAG4)
unnamed: FB2.2, J2.1 (VBUS)
unnamed: FB3.2, J3.1 (VBUS)
unnamed: FB4.2, J4.1 (VBUS)
unnamed: FB5.2, J5.1 (VBUS)
unnamed: TP1.1 (1_1), U1.13 (PECREQB)
unnamed: TP2.1 (1_1), U1.1 (SMIB)
unnamed: R6.2, U2.3 (~WP)
OCI1B: U1.26 (OCI1B); also elsewhere on the board
OCI2B: U1.24 (OCI2B); also elsewhere on the board
OCI3B: U1.22 (OCI3B); also elsewhere on the board
OCI4B: U1.20 (OCI4B); also elsewhere on the board
PECLKN: J1.A14 (REFCLK-), U1.5 (PECLKN)
PECLKP: J1.A13 (REFCLK+), U1.4 (PECLKP)
PERSTB: J1.A11 (~PERST), U1.2 (PERSTB)
PERXN: J1.B15 (PETn0), U1.11 (PERXN)
PERXP: J1.B14 (PETp0), U1.10 (PERXP)
PETXN: C27.2, J1.A17 (PERn0)
PETXP: C26.1, J1.A16 (PERp0)
PETX_HN: C27.1, U1.8 (PETXN)
PETX_HP: C26.2, U1.7 (PETXP)
PEWAKEB: J1.B11 (~WAKE), R1.1
PEWAKEB_H: R1.2, U1.3 (PEWAKEB)
PONRSTB: C28.1, D1.1 (A), R2.2, U1.14 (PONRSTB)
PPON1: U1.27 (PPON1); also elsewhere on the board
PPON2: U1.25 (PPON2); also elsewhere on the board
PPON3: U1.23 (PPON3); also elsewhere on the board
PPON4: U1.21 (PPON4); also elsewhere on the board
PRSNT: J1.A1 (~PRSNT1), J1.B17 (~PRSNT2)
SPICSB: R3.2, U1.17 (SPICSB), U2.1 (~CS)
SPISCK: R4.1, U1.18 (SPISCK), U2.6 (SCLK)
SPISI: R7.2, U1.19 (SPISI), U2.5 (SI)
SPISO: R5.2, U1.16 (SPISO), U2.2 (SO)
U2D1N: J5.2 (D-), U1.42 (U2DM1), U15.7, U15.8
U2D1P: J5.3 (D+), U1.41 (U2DP1), U15.6, U15.9
U2D2N: J4.2 (D-), U1.51 (U2DM2), U14.7, U14.8
U2D2P: J4.3 (D+), U1.50 (U2DP2), U14.6, U14.9
U2D3N: J3.2 (D-), U1.59 (U2DM3), U13.7, U13.8
U2D3P: J3.3 (D+), U1.58 (U2DP3), U13.6, U13.9
U2D4N: J2.2 (D-), U1.68 (U2DM4), U12.7, U12.8
U2D4P: J2.3 (D+), U1.67 (U2DP4), U12.6, U12.9
U3RXD1N: J5.5 (SSRX-), U1.39 (U3RXDN1), U15.4, U15.11
U3RXD1P: J5.6 (SSRX+), U1.38 (U3RXDP1), U15.3, U15.12
U3RXD2N: J4.5 (SSRX-), U1.48 (U3RXDN2), U14.4, U14.11
U3RXD2P: J4.6 (SSRX+), U1.47 (U3RXDP2), U14.3, U14.12
U3RXD3N: J3.5 (SSRX-), U1.56 (U3RXDN3), U13.4, U13.11
U3RXD3P: J3.6 (SSRX+), U1.55 (U3RXDP3), U13.3, U13.12
U3RXD4N: J2.5 (SSRX-), U1.65 (U3RXDN4), U12.4, U12.11
U3RXD4P: J2.6 (SSRX+), U1.64 (U3RXDP4), U12.3, U12.12
U3TXD1N: C44.1, J5.8 (SSTX-), U15.2, U15.13
U3TXD1P: C43.2, J5.9 (SSTX+), U15.1, U15.14
U3TXD1_HN: C44.2, U1.36 (U3TXDN1)
U3TXD1_HP: C43.1, U1.35 (U3TXDP1)
U3TXD2N: C42.1, J4.8 (SSTX-), U14.2, U14.13
U3TXD2P: C41.2, J4.9 (SSTX+), U14.1, U14.14
U3TXD2_HN: C42.2, U1.45 (U3TXDN2)
U3TXD2_HP: C41.1, U1.44 (U3TXDP2)
U3TXD3N: C40.1, J3.8 (SSTX-), U13.2, U13.13
U3TXD3P: C39.2, J3.9 (SSTX+), U13.1, U13.14
U3TXD3_HN: C40.2, U1.53 (U3TXDN3)
U3TXD3_HP: C39.1, U1.52 (U3TXDP3)
U3TXD4N: C38.1, J2.8 (SSTX-), U12.2, U12.13
U3TXD4P: C37.2, J2.9 (SSTX+), U12.1, U12.14
U3TXD4_HN: C38.2, U1.62 (U3TXDN4)
U3TXD4_HP: C37.1, U1.61 (U3TXDP4)
VCCCH1: FB5.1; also elsewhere on the board
VCCCH2: FB4.1; also elsewhere on the board
VCCCH3: FB3.1; also elsewhere on the board
VCCCH4: FB2.1; also elsewhere on the board

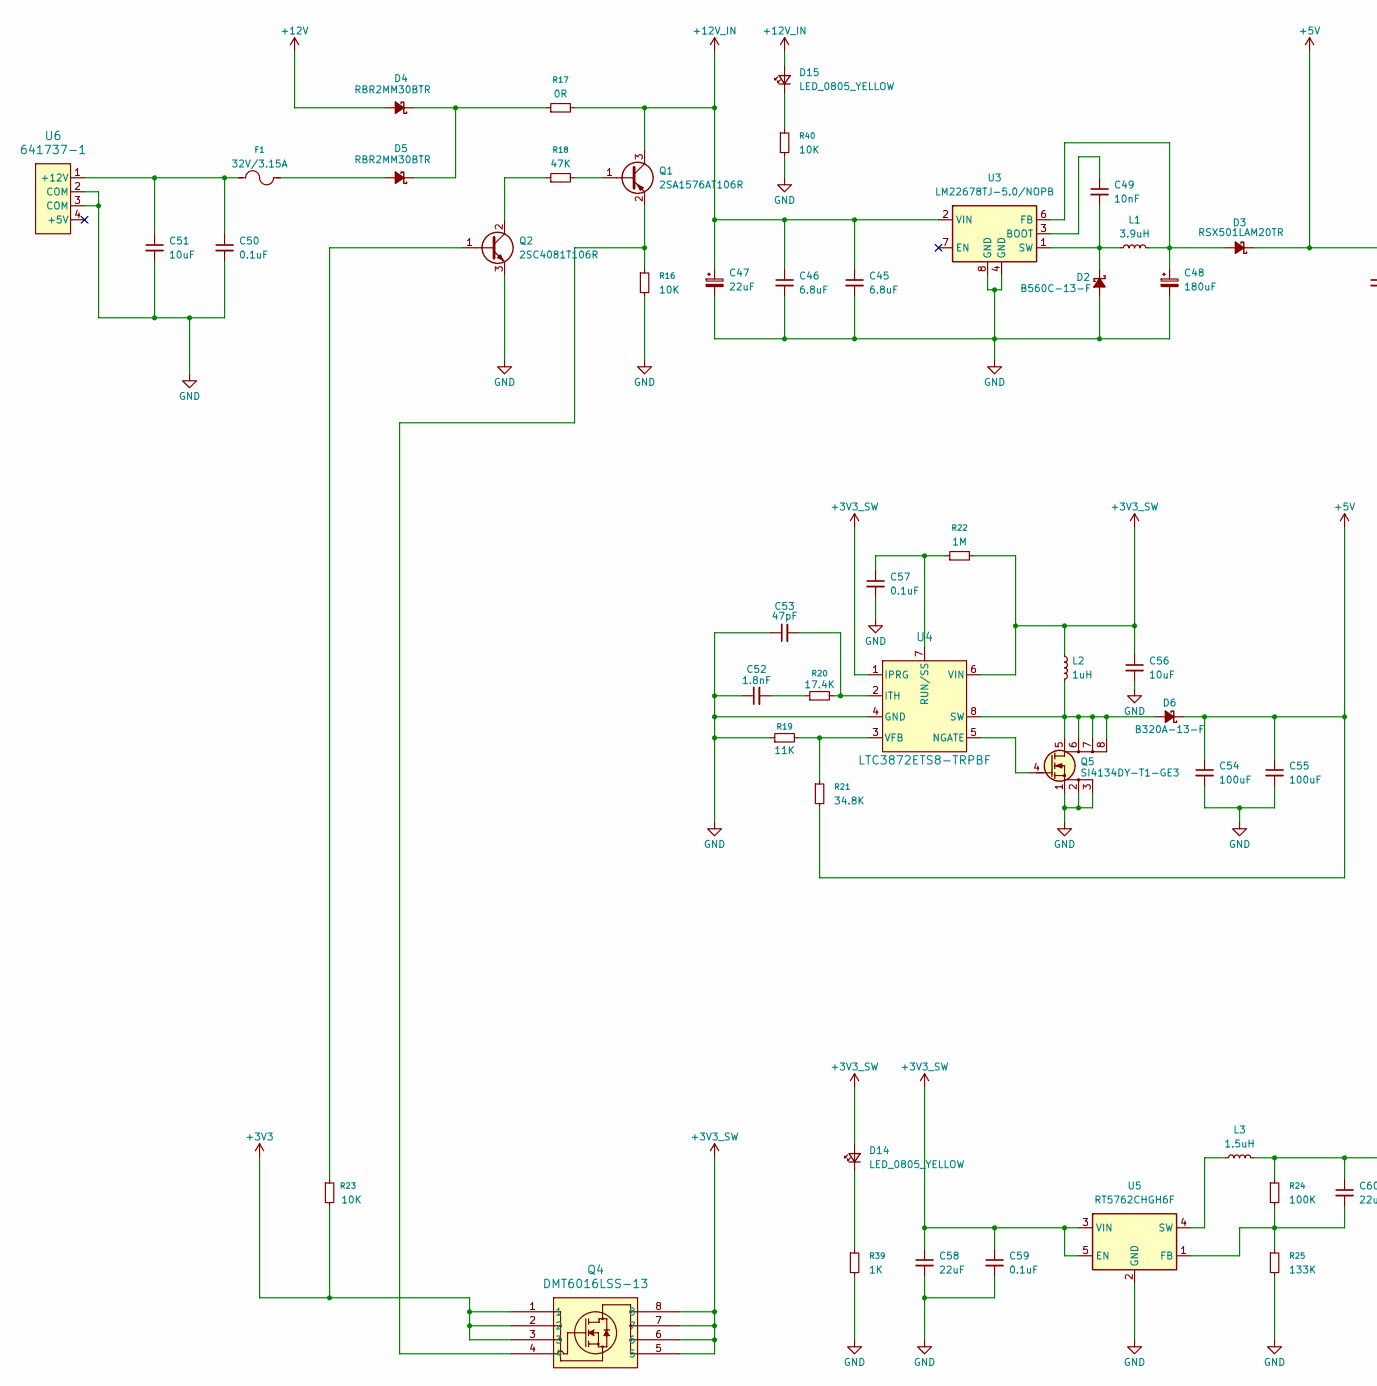
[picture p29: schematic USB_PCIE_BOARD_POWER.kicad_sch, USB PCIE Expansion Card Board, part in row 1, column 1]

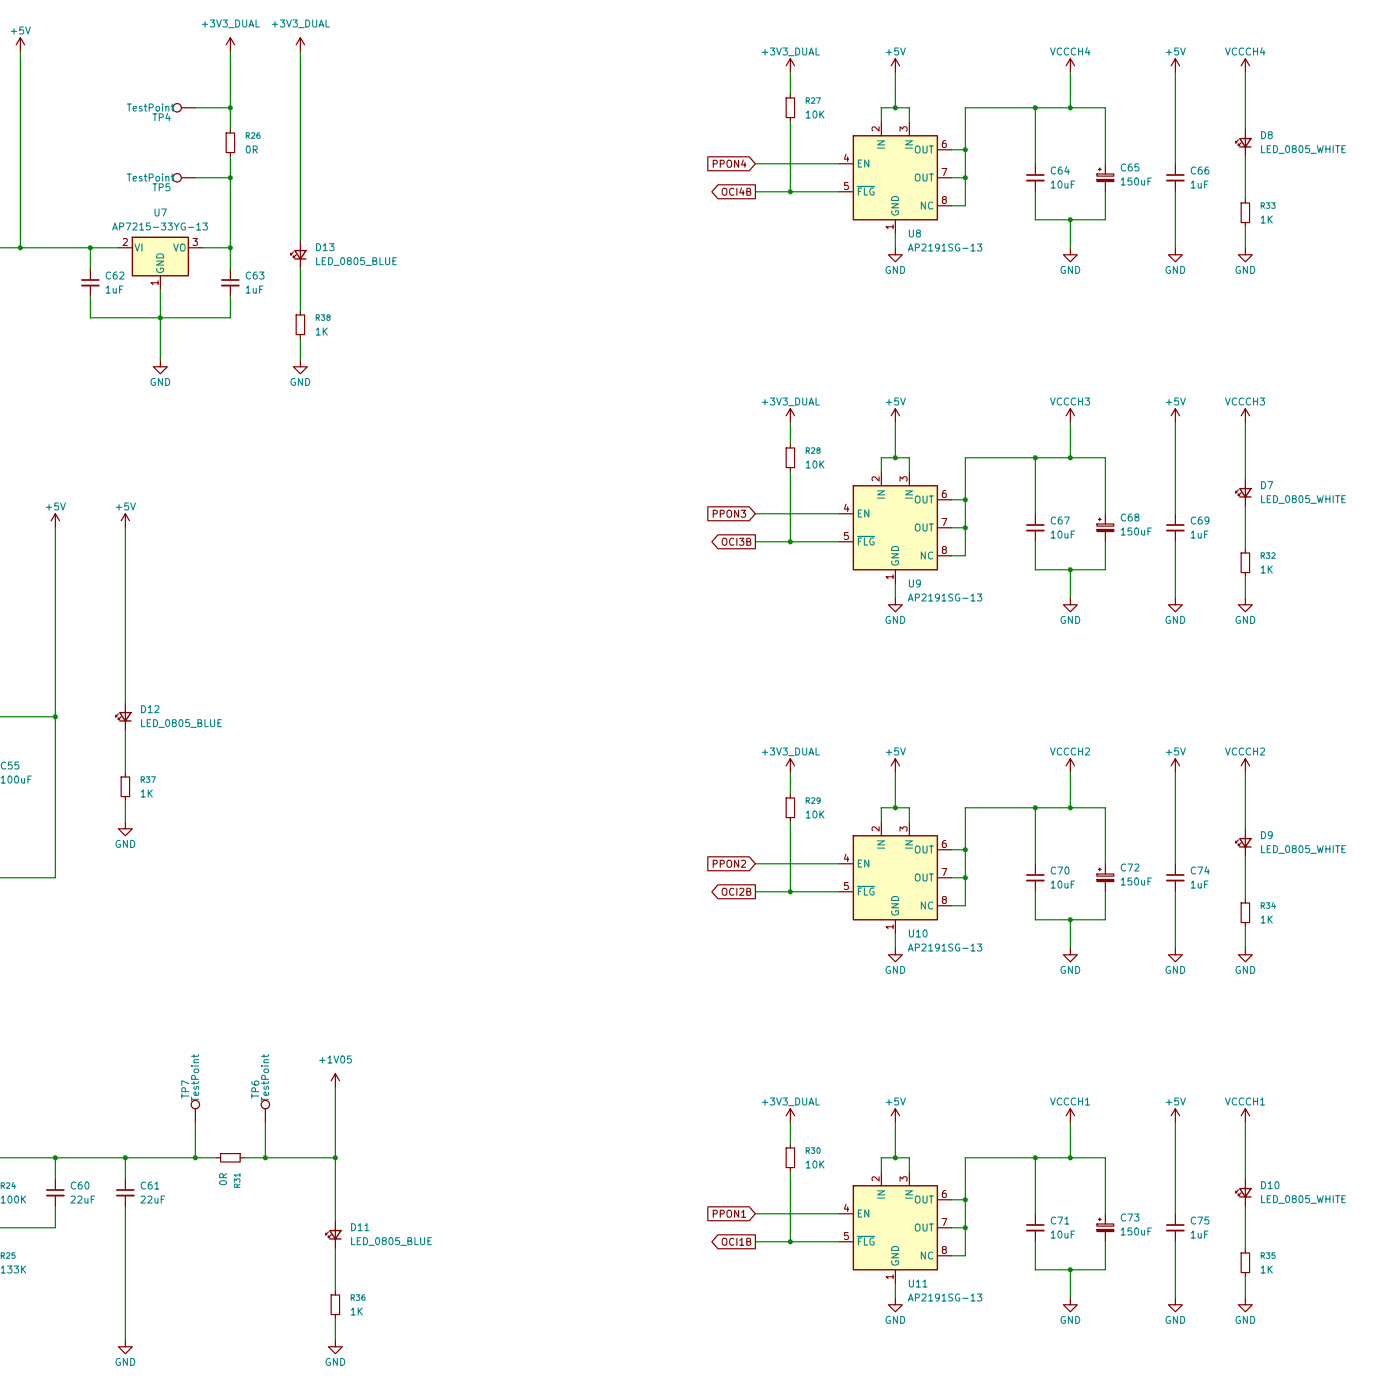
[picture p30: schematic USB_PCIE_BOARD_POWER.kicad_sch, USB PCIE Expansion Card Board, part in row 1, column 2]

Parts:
C45, C46: 6.8uF; C_1206_3216Metric_Pad1.33x1.80mm_HandSolder; Voltage Rating 35V; Manufacturer Part # C3216X7R1V685K160AC; DigiKey Part # 445-14808-1-ND
C47: 22uF; CP_Elec_6.3x5.9; Voltage Rating 50V; Manufacturer Part # EEE-FK1H220P; DigiKey Part # PCE3811CT-ND
C48: 180uF; CP_Elec_8x10.5; Voltage Rating 50V; Manufacturer Part # EEE-FN1H181UP; DigiKey Part # 10-EEE-FN1H181UPCT-ND
C49: 10nF; C_1206_3216Metric_Pad1.33x1.80mm_HandSolder; Voltage Rating 50V; Manufacturer Part # CC1206KRX7R9BB103; DigiKey Part # 311-1174-1-ND
C50, C57, C59: 0.1uF; C_0603_1608Metric_Pad1.08x0.95mm_HandSolder; Voltage Rating 50V; Manufacturer Part # CC0603KRX7R9BB104; DigiKey Part # C14663
C51, C56: 10uF; C_1206_3216Metric_Pad1.33x1.80mm_HandSolder; Voltage Rating 25V; Manufacturer Part # GRM319R61E106KA12D; DigiKey Part # 490-5525-1-ND
C52: 1.8nF; C_0402_1005Metric_Pad0.74x0.62mm_HandSolder; Voltage Rating 50V; Manufacturer Part # CC0402KRX7R9BB182; DigiKey Part # 311-1721-1-ND
C53: 47pF; C_0402_1005Metric_Pad0.74x0.62mm_HandSolder; Voltage Rating 50V; Manufacturer Part # CC0402JRNPO9BN470; DigiKey Part # 311-1021-1-ND
C54, C55: 100uF; C_1210_3225Metric_Pad1.33x2.70mm_HandSolder; Voltage Rating 10V; Manufacturer Part # CL32A107MPVNNNE; DigiKey Part # 1276-3364-1-ND
C58, C60, C61: 22uF; C_0603_1608Metric_Pad1.08x0.95mm_HandSolder; Voltage Rating 6.3V; Manufacturer Part # GRM188R60J226MEA0D; DigiKey Part # 490-7611-1-ND
C62, C63, C66, C69, C74, C75: 1uF; C_0603_1608Metric_Pad1.08x0.95mm_HandSolder; Voltage Rating 25V; Manufacturer Part # CL10B105KA8NNNC; DigiKey Part # 1276-1184-1-ND
C64, C67, C70, C71: 10uF; C_0805_2012Metric_Pad1.18x1.45mm_HandSolder; Voltage Rating 16V; Manufacturer Part # CC0805KKX7R7BB106; DigiKey Part # 311-3501-1-ND
C65, C68, C72, C73: 150uF; CP_Elec_8x6.9; Voltage Rating 16V; Manufacturer Part # 16SVPC150M; DigiKey Part # 493-3776-1-ND
D2: B560C-13-F; D_SMC_Handsoldering; Manufacturer Part # B560C-13-F; DigiKey Part # B560C-FDICT-ND
D3: RSX501LAM20TR; D_SOD-128; Manufacturer Part # RSX501LAM20TR; DigiKey Part # RSX501LAM20CT-ND
D4, D5: RBR2MM30BTR; D_SOD-123F; Manufacturer Part # RBR2MM30BTR; DigiKey Part # RBR2MM30BCT-ND
D6: B320A-13-F; D_SMA; Voltage Rating 20V; Current Rating 3A; Manufacturer Part # B320A-13-F; DigiKey Part # B320A-FDICT-ND
D7, D8, D9, D10: LED_0805_WHITE; LED_0805_2012Metric_Pad1.15x1.40mm_HandSolder; Voltage Rating 2.9V; Manufacturer Part # SMLMN2WB1CW1; DigiKey Part # 846-SMLMN2WB1CW1CT-ND
D11, D12, D13: LED_0805_BLUE; LED_0805_2012Metric_Pad1.15x1.40mm_HandSolder; Voltage Rating 2.9V; Manufacturer Part # SMLMN2BCTT86C; DigiKey Part # 846-1207-1-ND
D14, D15: LED_0805_YELLOW; LED_0805_2012Metric_Pad1.15x1.40mm_HandSolder; Voltage Rating 1.85V; Manufacturer Part # APTD2012LSYCK; DigiKey Part # 754-2045-1-ND
F1: 32V/3.15A; Fuse_0603_1608Metric_Pad1.05x0.95mm_HandSolder; Voltage Rating 32V; Current Rating 3.15A; Manufacturer Part # SF-0603S315-2; DigiKey Part # SF-0603S315-2CT-ND
L1: 3.9uH; IND_BOURNS_SRU8043; Current Rating 4.8A; Manufacturer Part # SRU8043-3R9Y; DigiKey Part # SRU8043-3R9YCT-ND
L2: 1uH; IND_SPM6530T-1R0M120; Current Rating 13A; Manufacturer Part # SPM6530T-1R0M120; DigiKey Part # 445-3880-1-ND
L3: 1.5uH; L_1008_2520Metric_Pad1.43x2.20mm_HandSolder; Current Rating 2.7A; Manufacturer Part # DFE252012F-1R5M=P2; DigiKey Part # 490-13054-1-ND
Q1: 2SA1576AT106R; SOT-323_SC-70; Manufacturer Part # 2SA1576AT106R; DigiKey Part # 2SA1576AT106RCT-ND
Q2: 2SC4081T106R; SOT-323_SC-70; Manufacturer Part # 2SC4081T106R; DigiKey Part # 2SC4081T106RCT-ND
Q4: DMT6016LSS-13; SO-8; Current Rating 9.2A; Manufacturer Part # DMT6016LSS-13; DigiKey Part # DMT6016LSS-13DICT-ND
Q5: SI4134DY-T1-GE3; SO-8_3.9x4.9mm_P1.27mm; Voltage Rating 30V; Current Rating 14A; Manufacturer Part # SI4134DY-T1-GE3; DigiKey Part # SI4134DY-T1-GE3CT-ND
R16, R23, R27, R28, R29, R30, R40: 10K; R_0603_1608Metric_Pad0.98x0.95mm_HandSolder; Tolerance 5%; Manufacturer Part # RK73B1JTTD103J; DigiKey Part # 2019-RK73B1JTTD103JCT-ND
R17, R26, R31: 0R; R_1206_3216Metric_Pad1.30x1.75mm_HandSolder; Manufacturer Part # RK73Z2BTTD; DigiKey Part # 2019-RK73Z2BTTDCT-ND
R18: 47K; R_0603_1608Metric_Pad0.98x0.95mm_HandSolder; Tolerance 5%; Manufacturer Part # RC0603JR-0747KL; DigiKey Part # 311-47KGRCT-ND
R19: 11K; R_0402_1005Metric_Pad0.72x0.64mm_HandSolder; Voltage Rating 50V; Manufacturer Part # AF0402FR-0711KL; DigiKey Part # 13-AF0402FR-0711KLCT-ND
R20: 17.4K; R_0402_1005Metric_Pad0.72x0.64mm_HandSolder; Voltage Rating 50V; Manufacturer Part # CRCW040217K4FKED; DigiKey Part # 541-17.4KLCT-ND
R21: 34.8K; R_0402_1005Metric_Pad0.72x0.64mm_HandSolder; Voltage Rating 50V; Manufacturer Part # CRCW040234K8FKED; DigiKey Part # 541-34.8KLCT-ND
R22: 1M; R_0603_1608Metric_Pad0.98x0.95mm_HandSolder; Tolerance 1%; Manufacturer Part # CRCW06031M00FKEA; DigiKey Part # 541-1.00MHCT-ND
R24: 100K; R_0603_1608Metric_Pad0.98x0.95mm_HandSolder; Tolerance 1%; Manufacturer Part # RC0603FR-07100KL; DigiKey Part # 311-100KHRCT-ND
R25: 133K; R_0603_1608Metric_Pad0.98x0.95mm_HandSolder; Tolerance 1%; Manufacturer Part # CRCW0603133RFKEA; DigiKey Part # 541-133HCT-ND
R32, R33, R34, R35, R36, R37, R38, R39: 1K; R_0603_1608Metric_Pad0.98x0.95mm_HandSolder; Tolerance 1%; Manufacturer Part # RC0603FR-071KL; DigiKey Part # 311-1.00KHRCT-ND
TP4, TP5, TP6, TP7: TestPoint; TestPoint_THTPad_1.0x1.0mm_Drill0.5mm
U3: LM22678TJ-5.0/NOPB; TO-263-7_TabPin8; Voltage Rating 42V; Current Rating 5A; Manufacturer Part # LM22678TJ-5.0/NOPB; DigiKey Part # 296-49671-1-ND
U4: LTC3872ETS8-TRPBF; TSOT-23-8; Manufacturer Part # LTC3872ETS8#TRPBF; DigiKey Part # LTC3872ETS8#TRPBFCT-ND
U5: RT5762CHGH6F; SOT-563; Voltage Rating 6V; Current Rating 2A; Manufacturer Part # RT5762CHGH6F; DigiKey Part # 1028-RT5762CHGH6FCT-ND
U6: 641737-1; 641737-1_TYC; Manufacturer Part # 641737-1; DigiKey Part # A25430-ND
U7: AP7215-33YG-13; SOT-89-3; Current Rating 600mA; Manufacturer Part # AP7215-33YG-13; DigiKey Part # AP7215-33YG-13DICT-ND
U8, U9, U10, U11: AP2191SG-13; HSOP-8-1EP_3.9x4.9mm_P1.27mm_EP2.3x2.3mm; Manufacturer Part # AP2191SG-13; DigiKey Part # AP2191SGDICT-ND

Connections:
+1V05: D11.2 (A), R31.1, TP6.1 (1_1); also elsewhere on the board
+3V3: Q4.1, Q4.2, Q4.3, R23.2; also elsewhere on the board
+3V3_DUAL: D13.2 (A), R26.1, R27.1, R28.1, R29.1, R30.1, TP4.1 (1_1); also elsewhere on the board
+3V3_SW: C56.1, C58.1, C59.1, D14.2 (A), L2.1, Q4.5, Q4.6, Q4.7, Q4.8, R22.2, U4.1 (IPRG), U4.6 (VIN), U5.3 (VIN), U5.5 (EN)
+5V: C54.1, C55.1, C62.1, C66.1, C69.1, C74.1, C75.1, D3.1 (K), D6.1 (K), D12.2 (A), R21.2, U7.2 (VI), U8.2 (IN), U8.3 (IN), U9.2 (IN), U9.3 (IN), U10.2 (IN), U10.3 (IN), U11.2 (IN), U11.3 (IN)
+12V: D4.2 (A); also elsewhere on the board
+12V_IN: C45.1, C46.1, C47.1, D15.2 (A), Q1.3 (C), R17.2, U3.2 (VIN)
GND: C45.2, C46.2, C47.2, C48.2, C50.2, C51.2, C52.1, C53.1, C54.2, C55.2, C56.2, C57.2, C58.2, C59.2, C61.2, C62.2, C63.2, C64.2, C65.2, C66.2, C67.2, C68.2, C69.2, C70.2, C71.2, C72.2, C73.2, C74.2, C75.2, D2.2 (A), Q2.3 (E), Q5.1 (S), Q5.2 (S), Q5.3 (S), R16.2, R19.1, R25.2, R32.2, R33.2, R34.2, R35.2, R36.2, R37.2, R38.2, R39.2, R40.2, U3.4 (GND), U3.8 (GND), U4.4 (GND), U5.2 (GND), U6.2 (COM), U6.3 (COM), U7.1 (GND), U8.1 (GND), U9.1 (GND), U10.1 (GND), U11.1 (GND); also elsewhere on the board
unnamed: C52.2, R20.1
unnamed: C60.1, C61.1, L3.2, R24.1, R31.2, TP7.1 (1_1)
unnamed: C49.2, D2.1 (K), L1.1, U3.1 (SW)
unnamed: C48.1, D3.2 (A), L1.2, U3.6 (FB)
unnamed: D4.1 (K), D5.1 (K), R17.1
unnamed: D5.2 (A), F1.2
unnamed: D6.2 (A), L2.2, Q5.5 (D), Q5.6 (D), Q5.7 (D), Q5.8 (D), U4.8 (SW)
unnamed: D7.1 (K), R32.1
unnamed: D8.1 (K), R33.1
unnamed: D9.1 (K), R34.1
unnamed: D10.1 (K), R35.1
unnamed: D11.1 (K), R36.1
unnamed: D12.1 (K), R37.1
unnamed: D13.1 (K), R38.1
unnamed: D14.1 (K), R39.1
unnamed: D15.1 (K), R40.1
unnamed: Q1.1 (B), R18.2
unnamed: Q1.2 (E), Q4.4, R16.1
unnamed: Q2.1 (B), R23.1
unnamed: Q2.2 (C), R18.1
unnamed: Q5.4 (G), U4.5 (NGATE)
unnamed: C49.1, U3.3 (BOOT)
unnamed: C53.2, R20.2, U4.2 (ITH)
unnamed: C57.1, R22.1, U4.7 (RUN/SS)
unnamed: R19.2, R21.1, U4.3 (VFB)
unnamed: C60.2, R24.2, R25.1, U5.1 (FB)
unnamed: L3.1, U5.4 (SW)
unnamed: C50.1, C51.1, F1.1, U6.1 (+12V)
unnamed: C63.1, R26.2, TP5.1 (1_1), U7.3 (VO)
OCI1B: R30.2, U11.5 (~FLG); also elsewhere on the board
OCI2B: R29.2, U10.5 (~FLG); also elsewhere on the board
OCI3B: R28.2, U9.5 (~FLG); also elsewhere on the board
OCI4B: R27.2, U8.5 (~FLG); also elsewhere on the board
PPON1: U11.4 (EN); also elsewhere on the board
PPON2: U10.4 (EN); also elsewhere on the board
PPON3: U9.4 (EN); also elsewhere on the board
PPON4: U8.4 (EN); also elsewhere on the board
VCCCH1: C71.1, C73.1, D10.2 (A), U11.6 (OUT), U11.7 (OUT), U11.8 (NC); also elsewhere on the board
VCCCH2: C70.1, C72.1, D9.2 (A), U10.6 (OUT), U10.7 (OUT), U10.8 (NC); also elsewhere on the board
VCCCH3: C67.1, C68.1, D7.2 (A), U9.6 (OUT), U9.7 (OUT), U9.8 (NC); also elsewhere on the board
VCCCH4: C64.1, C65.1, D8.2 (A), U8.6 (OUT), U8.7 (OUT), U8.8 (NC); also elsewhere on the board

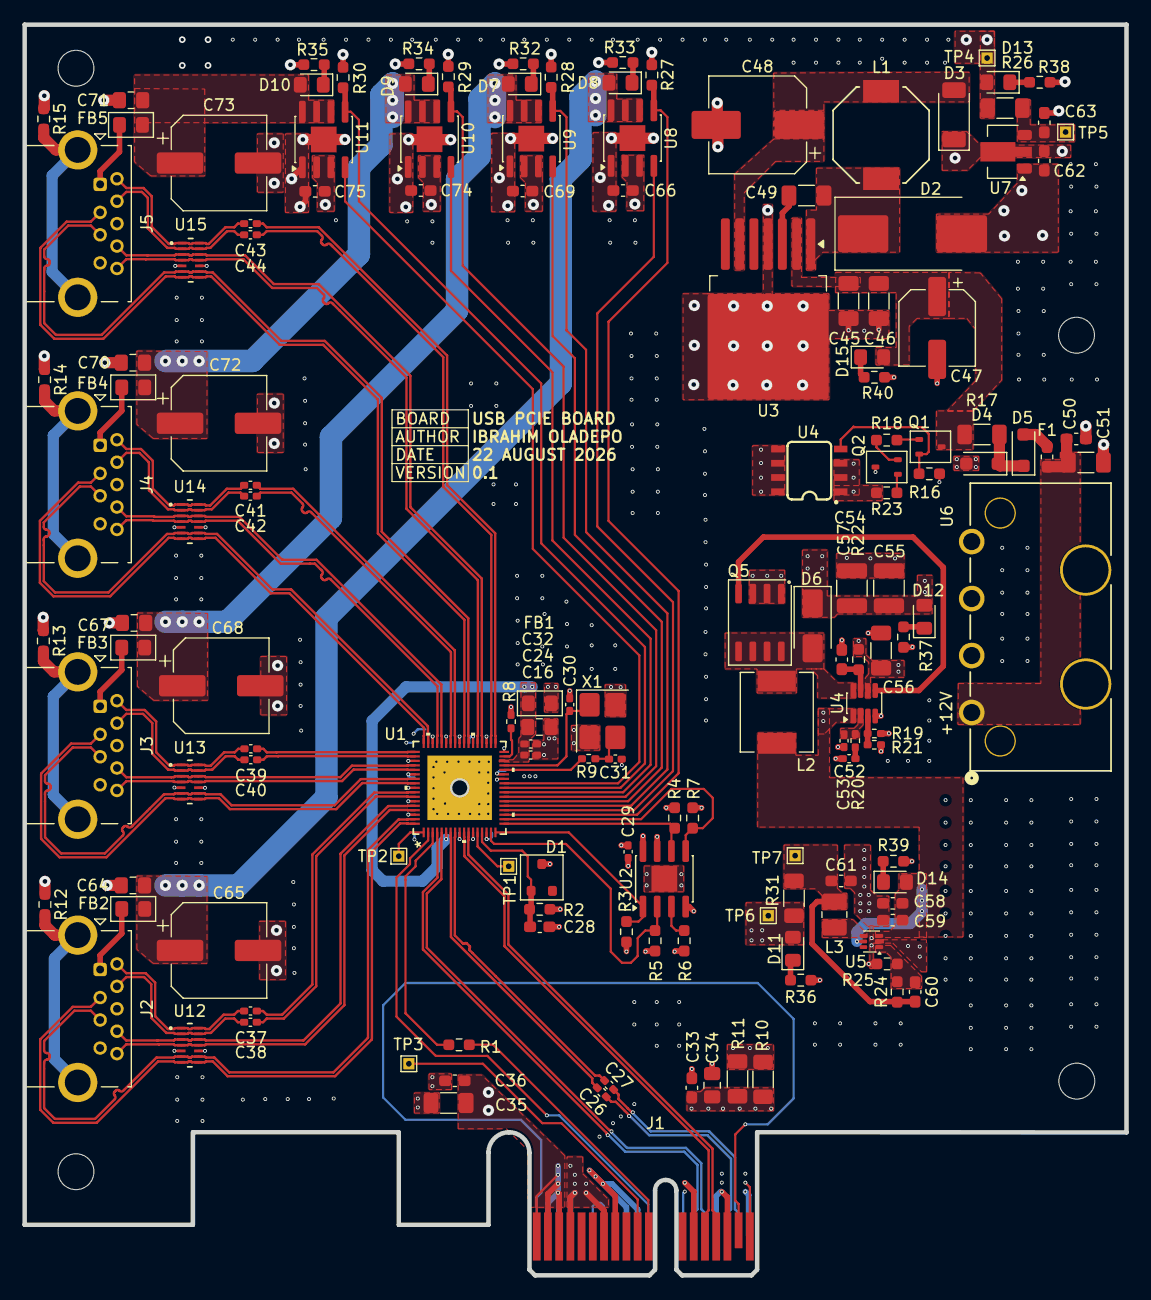
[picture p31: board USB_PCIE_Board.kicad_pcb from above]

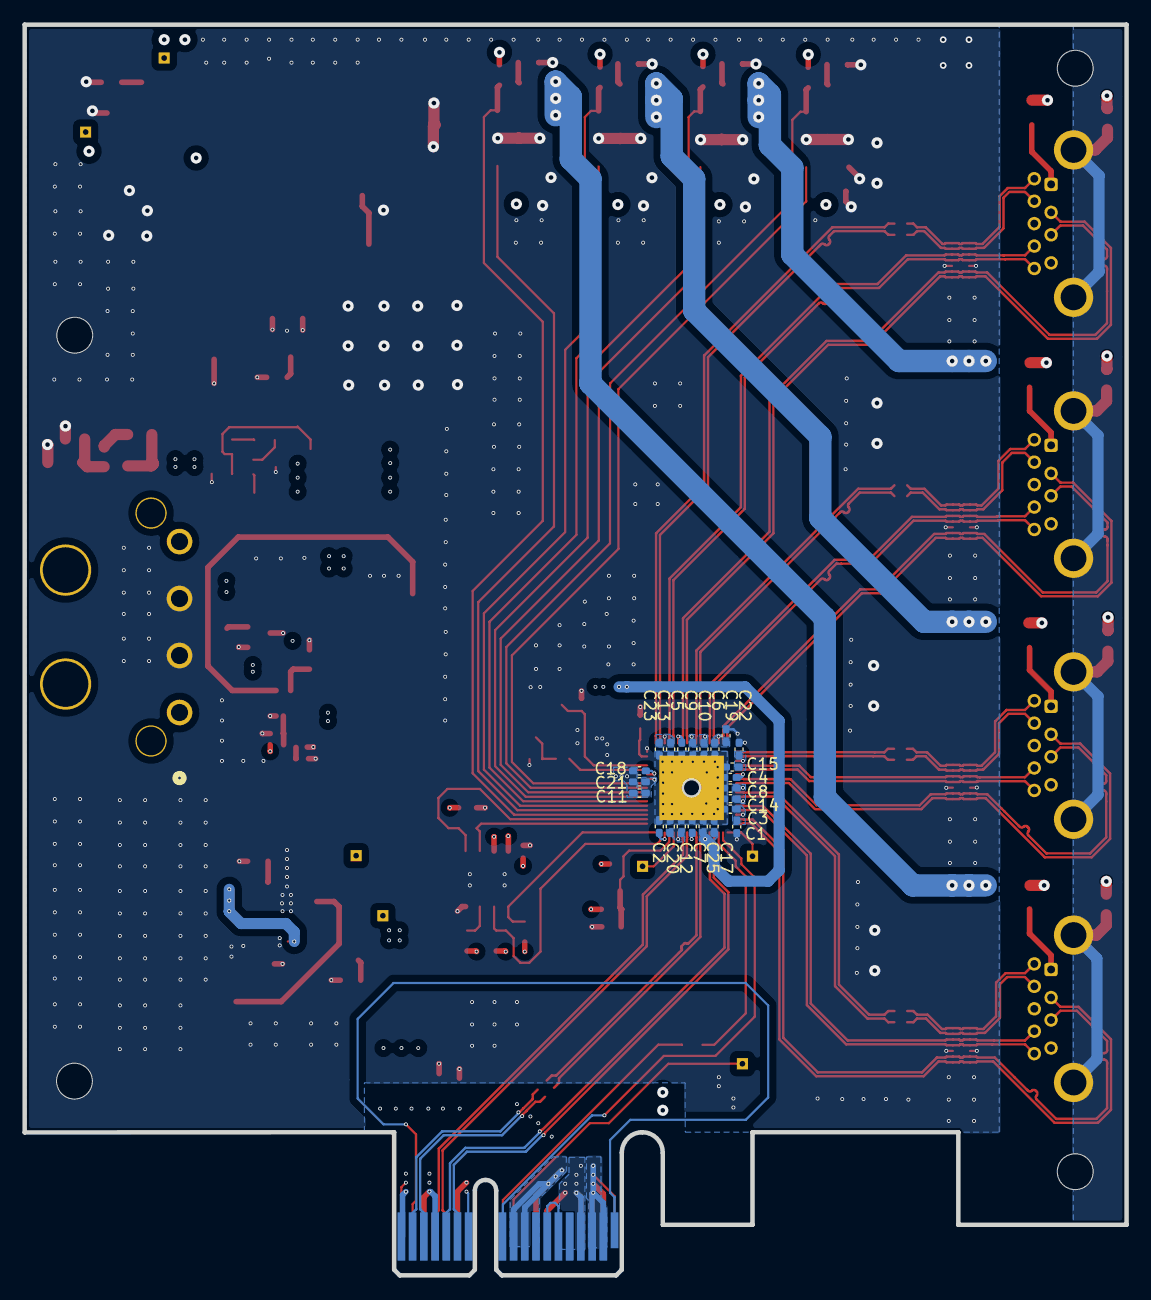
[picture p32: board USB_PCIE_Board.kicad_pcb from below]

Board: 4 copper layers, 98.2 x 111.5 mm, 175 parts (23 on the bottom side), 114 nets.

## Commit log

2026-08-11 Initial Commit for Project Creation
    [USB_PCIE_Board.kicad_pcb, USB_PCIE_Board.kicad_sch]
2026-08-11 Populated host schematic and power caps
    [USB_PCIE_BOARD_POWER.kicad_sch, USB_PCIE_Board.kicad_sch]
2026-08-11 Populated all connections and components in the host controller page
    [USB_PCIE_Board.kicad_sch]
2026-08-14 Added power conversion circuits
    [USB_PCIE_BOARD_POWER.kicad_sch, USB_PCIE_Board.kicad_sch]
2026-08-14 Fix changes suggested by Claude review; added schematic and netlist to document folder
    [USB_PCIE_BOARD_POWER.kicad_sch, USB_PCIE_Board.kicad_sch]
2026-08-15 Add indicator LEDs and run ERC
    [USB_PCIE_BOARD_POWER.kicad_sch]
2026-08-15 Add edge cut shape to PCB and fix unconnected shape error
    [UNG8315_D_EDGE_Only_Short.dxf, USB_PCIE_Board.kicad_pcb]
2026-08-16 Place all components except host chip decoupling caps and the crystal circuit.
    [USB_PCIE_BOARD_POWER.kicad_sch, USB_PCIE_Board.kicad_pcb, USB_PCIE_Board.kicad_sch]
2026-08-16 Placed all parts on PCB
    [USB_PCIE_Board.kicad_pcb]
2026-08-18 Complete first pass of routing all nets without DRC
    [USB_PCIE_Board.kicad_pcb, USB_PCIE_Board.kicad_sch]
2026-08-18 Fix some DRC no-connect issues
    [USB_PCIE_Board.kicad_pcb]
2026-08-19 Replaced and rerouted host chip decoupling capacitors
    [USB_PCIE_Board.kicad_pcb]
2026-08-20 Fix skew on differential pair lines and fix DRC errors from Silkscreen overlaps
    [USB_PCIE_Board.kicad_pcb]
2026-08-22 Stop tracking .history as a submodule; keep KiCad local-history backups out of the repo
    .history is KiCad's own local-history git repo used for automatic
    recovery snapshots. git had picked it up as a gitlink (submodule
    reference) with no .gitmodules entry, which is not intentional.
    Untrack it and ignore the directory outright; the backups themselves
    remain untouched on disk.
2026-08-22 Add mounting hole symbols to schematic and continue PCB DRC cleanup
    Sync schematic with the board by adding H1-H4 mounting holes, and
    continue working through DRC violations (dangling vias, hole
    clearance, footprint mismatches) on the PCB.
    [USB_PCIE_Board.kicad_pcb, USB_PCIE_Board.kicad_sch]
2026-08-22 Add PCB design review checklist derived from Altium's checklist article
    Source PDF saved alongside for reference; the markdown checklist
    covers pre-review, layers, signal path, components, testing,
    protection/EMI/EMC, and panel sections to work through during design
    review.
2026-08-22 Add fabrication export and local tooling config
    Track the generated gerbers/BOM/position files/netlist under
    production/ from the fabrication-toolkit export, its options file,
    the latest DRC violations report, and the local KiCad MCP server
    config used for this project.
    [USB_PCIE_Board-B_Cu.gbl, USB_PCIE_Board-B_Mask.gbs, USB_PCIE_Board-B_Paste.gbp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]
2026-08-23 Mark reviewed checklist items as checked off
    Update checkbox state on the PCB design review checklist as items
    get worked through.
2026-08-23 Fix DRC errors: dangling vias, hole clearance, and courtyard issues
    Address the bulk of the outstanding DRC violations flagged in the
    design review, including dangling stitching vias and tight hole
    clearances around U1's decoupling network.
    [USB_PCIE_Board.kicad_pcb]
2026-08-23 Write project README
    Replace the placeholder with an overview of the board: PCIe x1 to
    4-port USB 3.0 expansion card built around the Renesas UPD720201
    host controller, key component roles, and repo layout.
2026-08-23 Move PCIe diff-pair decoupling caps closer per host chip guidance; add fab tables to drawing layer
    Relocate the capacitors on the PCIe differential pair closer to the
    card edge per the host chip manufacturer's layout guidance, and add
    stackup/fabrication info tables to the drawing layer. Regenerate
    fabrication outputs (gerbers, drill files, netlist, BOM) to match.
    [USB_PCIE_Board-B_Cu.gbl, USB_PCIE_Board-B_Mask.gbs, USB_PCIE_Board-B_Paste.gbp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]
2026-08-25 Add BOM sourcing audit against JLCPCB/LCSC stock and MOQ
    Document per-part MOQ, stock, library type, and suggested
    lower-friction alternatives from the JLCPCB parts database, with
    notes on the parts needing manual follow-up (crystal, thin-stock
    resistor group, unmatched LCSC numbers).
2026-08-25 Regenerate fabrication outputs and add impedance/fab reference docs
    Update gerbers, BOM, positions, and netlist to match the latest PCB
    edits, including the new User Drawings layer. Add the JLCPCB
    impedance calculation screenshot and a one-page fabrication guide for
    reference.
    [USB_PCIE_Board-B_Cu.gbl, USB_PCIE_Board-B_Mask.gbs, USB_PCIE_Board-B_Paste.gbp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]
2026-09-11 Add printable PDF of the component tray label and lookup table
    Export both print views (150x150mm cut-out label, BOM-to-compartment
    lookup table) from the interactive tray layout page as a single PDF
    for offline reference during hand assembly.
2026-09-12 Add board renders and component tray STLs to README
    Show top/bottom isometric Blender renders of the board and add a
    component sorting tray section (box + lid STLs from box-stl-generator,
    with rendered previews of each) linking to the printable tray layout.
    [PCB_Render.blend, box_150x150x10.stl, lid_150x150x10.stl]
2026-09-16 Add uPD720201 firmware/driver setup doc (Linux + Windows)
    Documents the manual firmware install required for the xhci-pci-renesas
    driver on Linux, plus the Windows Update + Renesas driver install that
    worked without a manual firmware step.
2026-09-16 Inline uPD720201 firmware/driver setup into README
    Fold the Linux firmware install steps and Windows driver note directly
    into the README instead of a separate Doc file.
2026-09-17 Add assembled v0.1 board photos to README with R25 bodge-fix story
    Top/bottom photos of the first populated board, plus a short writeup
    of the R25 133ohm-vs-133k feedback resistor error and the through-hole
    bodge fix visible in the top view.
2026-09-17 Add remaining v0.1 assembly photos, interactive BOM, and JLCPCB stencil verification files
    [SO12608240633-1.DXF, SO12608240633-2.DXF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]
2026-09-21 Correct U1 part number to UPD720201K8-701-BAC-A; fix silkscreen; add LCSC order BOM
    Schematic symbol/value/datasheet now match the part actually ordered and
    populated. Regenerated schematic PDF and added the final LCSC BOM CSV.
    [USB_PCIE_Board.kicad_pcb, USB_PCIE_Board.kicad_sch, USB_PCIE_Board_LCSC_Final_BOM.csv]
2026-09-21 README: running-in-PC photos, CrystalDiskMark results, known issues; fix U1 part number
    Documents the PCIe riser setup, the 100k+33k R25 fix, disk benchmark,
    and the D11 1.05V indicator LED (Vf 2.9V) issue. Uses a downscaled copy
    of the annotated photo since the original is 65MB.
2026-09-21 README: add design approach section; list 2D/Photos and bom in repo layout
